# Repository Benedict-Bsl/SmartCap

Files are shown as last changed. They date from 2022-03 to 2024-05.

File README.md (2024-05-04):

# SmartCap is an IOT device
as a proof of concept device, it was aim to demonstate how with a few features,
a bottle could be smart in helping older people or pantient with periodic memory loss.

#### Features:
  - Cloud data loggingd
  - indicate the quantity/number of pills incide the bottle on mobile phone
  - allow substraction of remaining pills
  - notify the user the time frame for the next dosage
  - notify when the bottle is empty.
  - gps location and buzzer alarm sound, incase the bottle is misplaced or lost.

#### Folder contents:
  - TrackRXFirmware_noSerial : complete device firmware
  - TraCkRXFirmware : debugging code
  - Platformio : an extension for mobile network connectivity with a gsm module
  - Misceleanious: backup and obsole files
  - Firware : different firmware for different modules such as gsm gps
  - Documents : in relation of the developement process
  - DFRobot_ID809-master : library for finger print sensor
  - d1Mini_serverAccess : Cloud server access firmware
  - cv : dataset for pill image dettection
  - circuitry : circuit and related files
##### :) don't mind the huge size of the bottle ( or the cap(the green/white thing)... it's only a prototype ... ahaha, wait,.. it's a proof of concepts!
The above project is proprietary/private , for non commercial usage. Make sure you site the author in any related work. 
Interests, critics...? on the project?, 
please contact the author: benobusole@gmail.com | migarajun@outlook.com

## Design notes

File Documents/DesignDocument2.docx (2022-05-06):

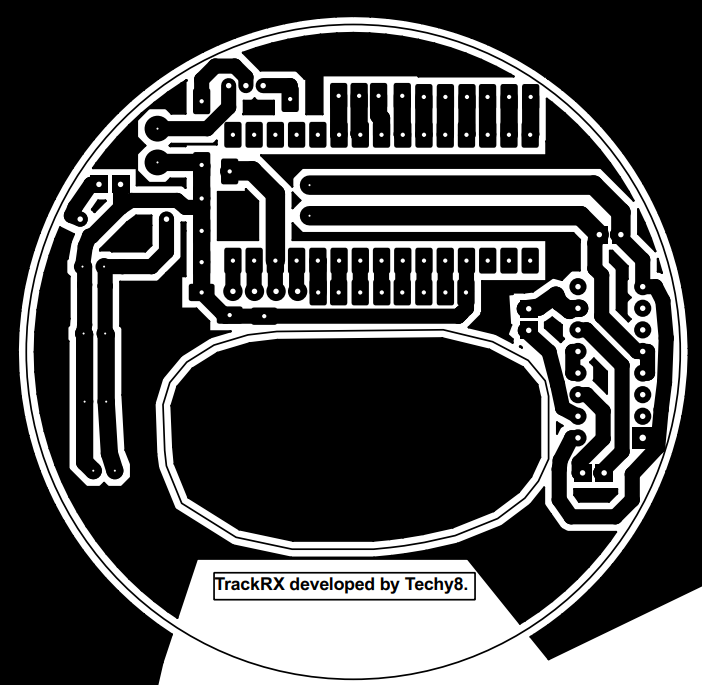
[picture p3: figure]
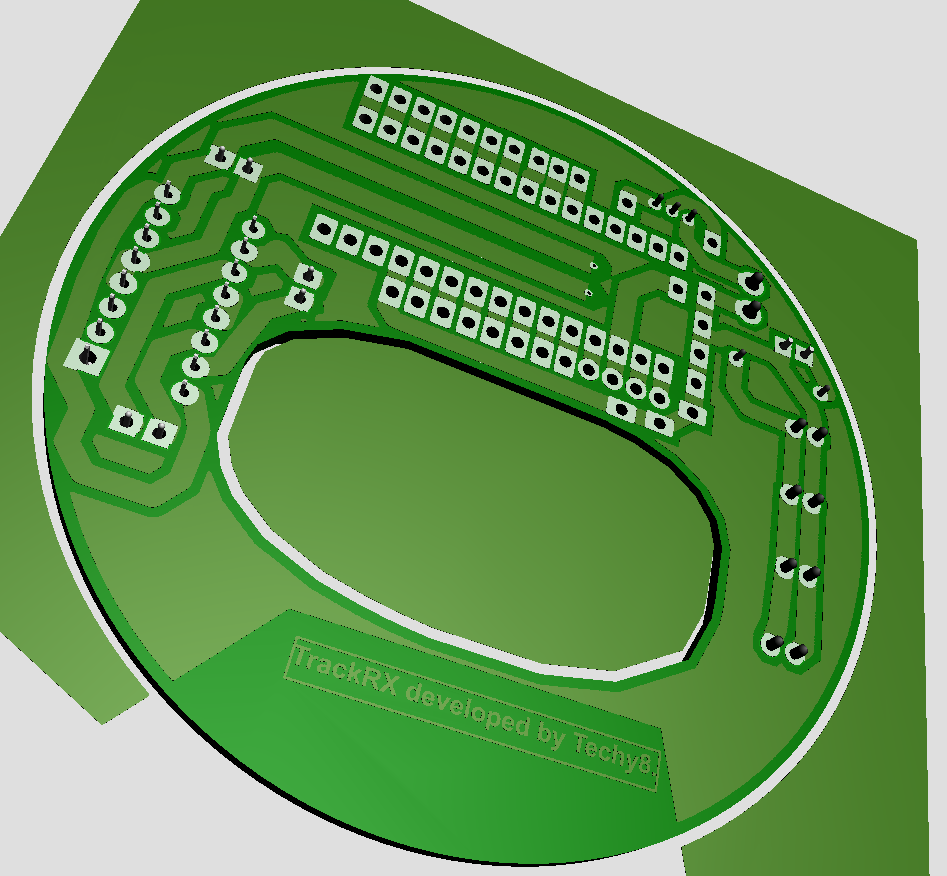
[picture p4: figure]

Main controller Power supply route Motor/locking control Sensors and Communication Section (net, gps..) | Printed Circuit Board | This is the main circuit board for the trackRX cap design with different components connected together as shown.

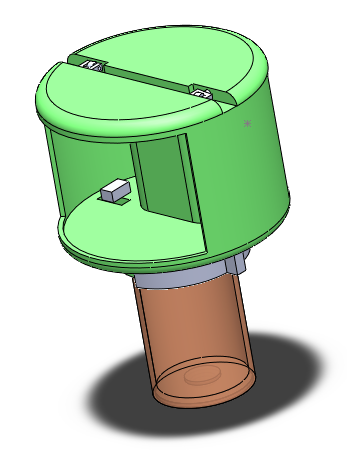
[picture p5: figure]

| Cup designs | The current cup design, with the front, back and top.

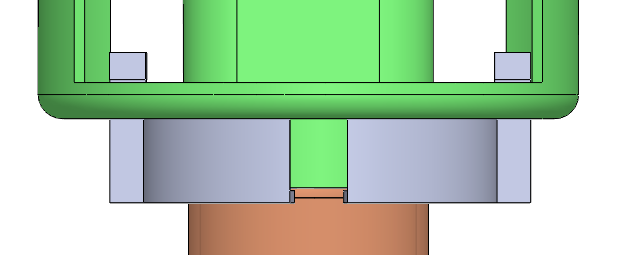
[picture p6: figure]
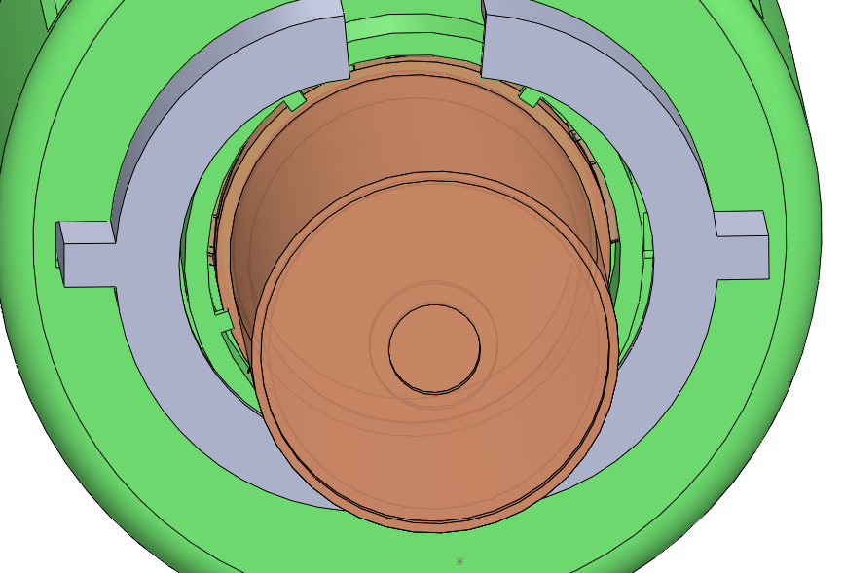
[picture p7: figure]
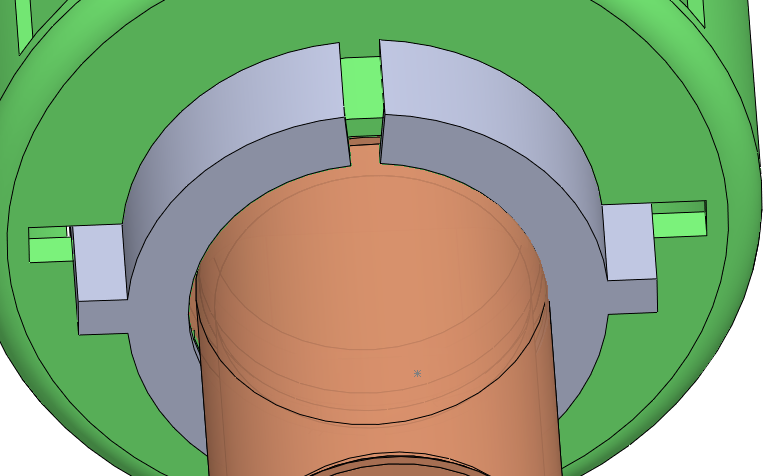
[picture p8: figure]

Open Front Closed | Bottom lock Mechanism | The current bottom mechanism design. the lock is remotely activated from the dashboard.

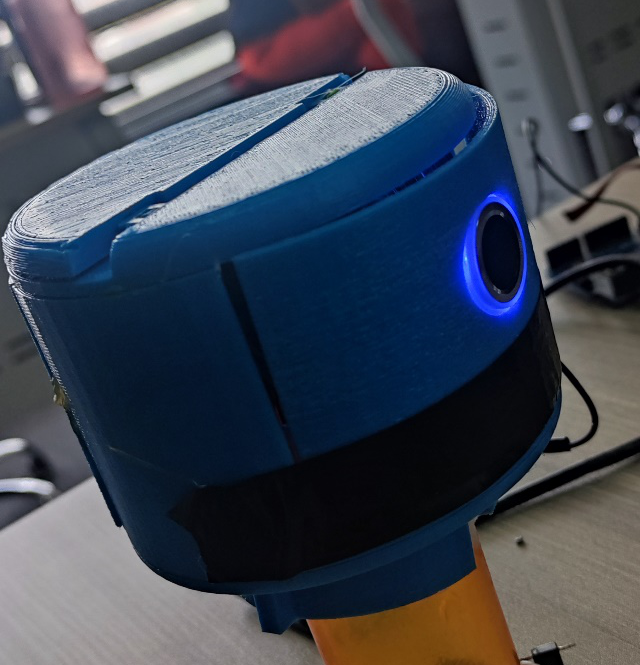
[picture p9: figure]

| Device during trial(current state). | Smart cap.

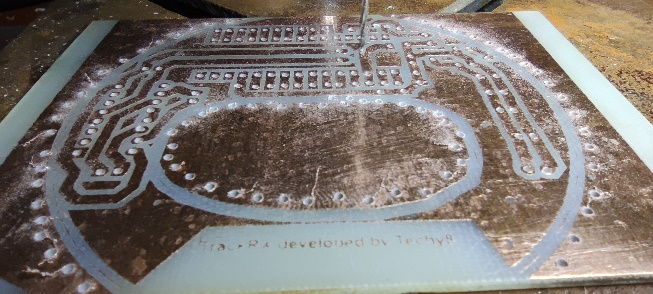
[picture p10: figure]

| Drilling of the trackRX pcB | TrackRX pcb.

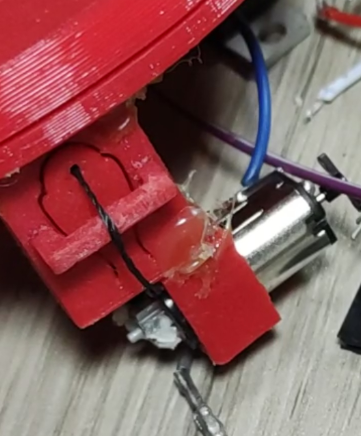
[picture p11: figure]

| On device top locking mechanism. (Early version) | Attract and retract based on given command.

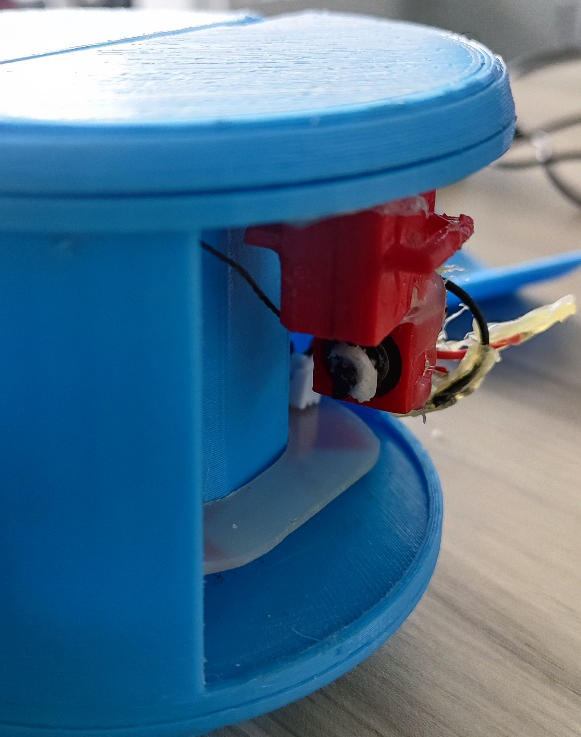
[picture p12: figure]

| Top Locking mechanism | Closed(if no fingerprint has been detected)

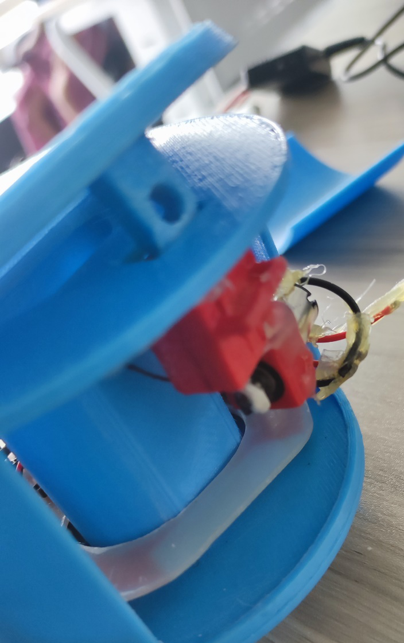
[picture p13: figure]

| Top locking Mechanism | Opened if finger print has been identified.

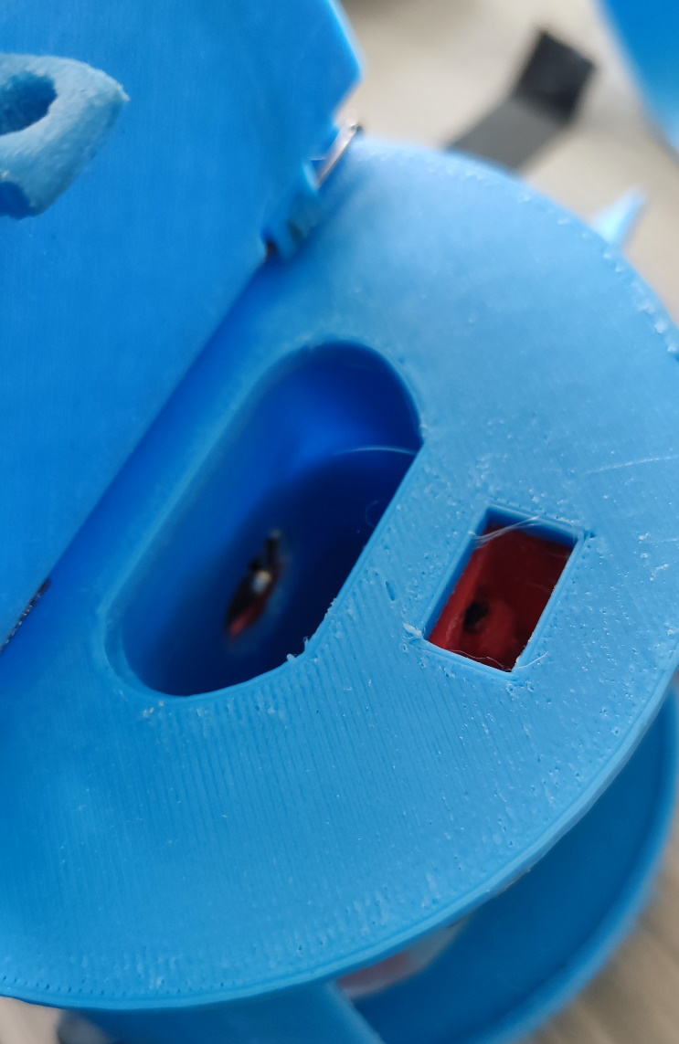
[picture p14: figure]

Sensory Point | Pills extraction point | Sensor included below (later will be covered with transparent glass)

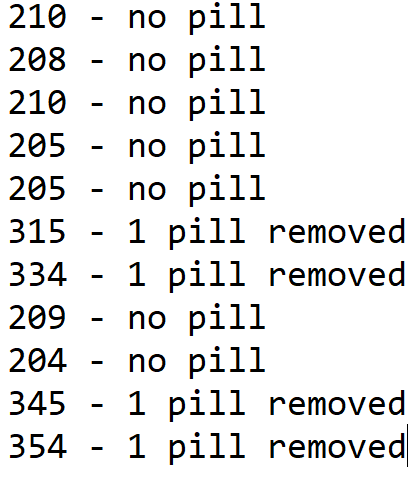
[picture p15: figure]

| Sensor output variations. | From 210-300 no pills have been detected From 310, 340 etc., a pill has been detect coming out of the bottle.

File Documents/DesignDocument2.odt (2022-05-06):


Main controller Power supply route Motor/locking control Sensors and Communication Section (net, gps..) | Printed Circuit Board | This is the main circuit board for the trackRX cap design with different components connected together as shown.


| Cup designs | The current cup design, with the front, back and top.


Open Front Closed | Bottom lock Mechanism | The current bottom mechanism design. the lock is remotely activated from the dashboard.


| Device during trial | Smart cap.


| Drilling of the trackRX pcB | TrackRX pcb.


| On device top locking mechanism | Attract and retract based on given command.

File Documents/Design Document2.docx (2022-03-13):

POC DESIGN DOCUMENT

For a smart cup on a bottle.

FEBRUARY 22, 2022

TECHY8

# Introduction

This document specifies key conceptual design for a smart pill cup, proof of concept design. The smart cup will be able to provide features such as: keeping track of the cup opening/closing, fingerprint reader, dosage trackage, content counter of the pills inside the bottle to which it is attached, and bottle location signaling; all provided to a website or a mobile application.

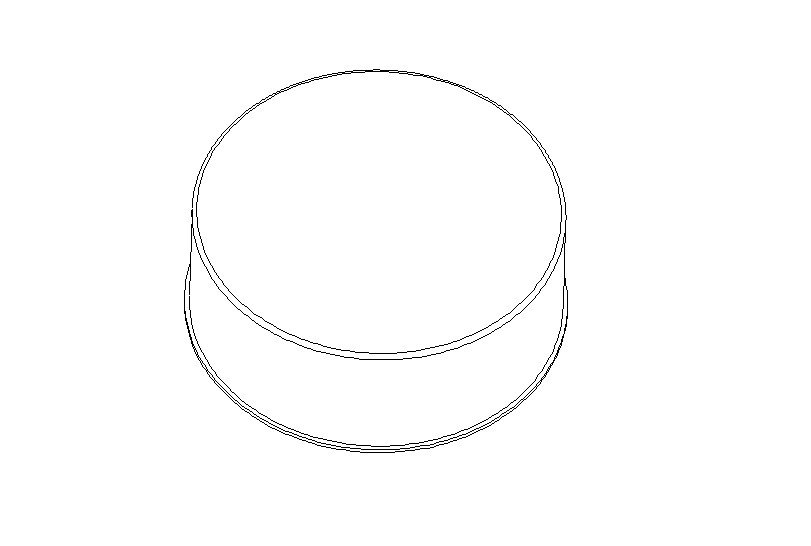
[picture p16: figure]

Figure 1 : POC cup

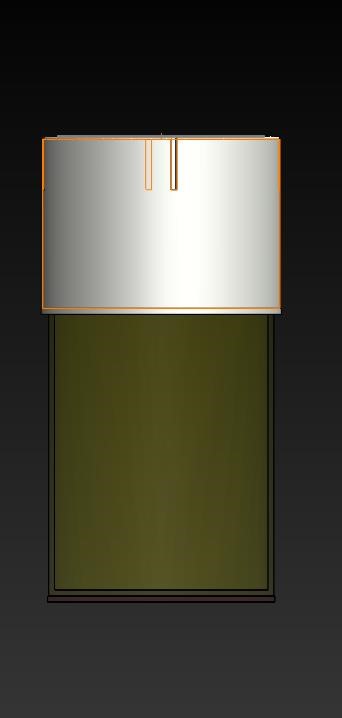
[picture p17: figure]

Figure 2 Cup on bottle

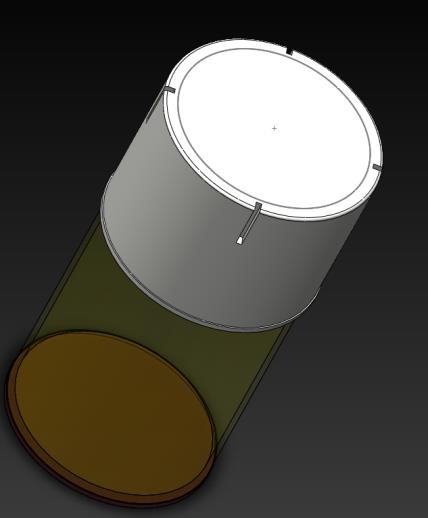
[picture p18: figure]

Figure 3 Cap and bottle (view)

## Tracking Cap Opening

A trigger switch placed on the cup will be able to detect when the bottles’ cup is opened or closed. The cup can only be opened if the fingerprint has successfully identified the owner or patient to whom the bottle belongs to.

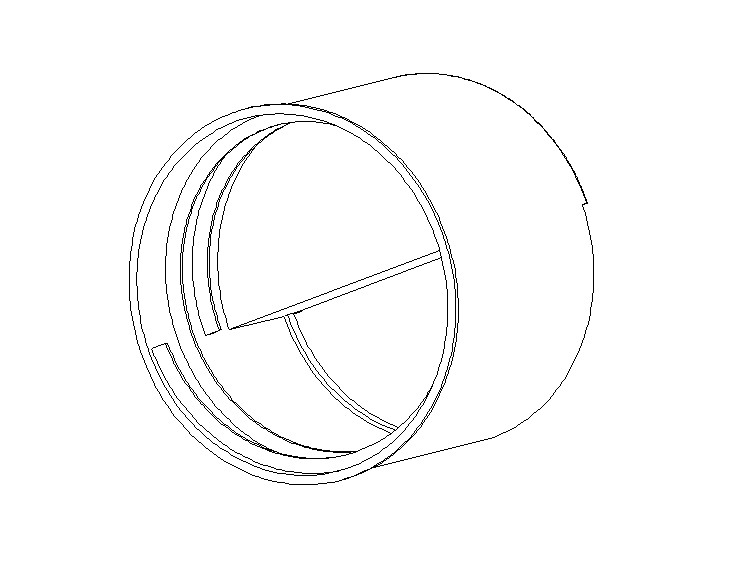
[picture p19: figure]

C

ont

act

switch

Figure 4 : Cup thread

## Finger print recognition

The finger print sensor, placed upon the cup will be able to identify the cap owner and that only, after the biometrical data has been retrieved and assured to be genuine, then a signal will be released by an imbedded microcontroller that will enable the locking mechanism of the bottle to be opened.

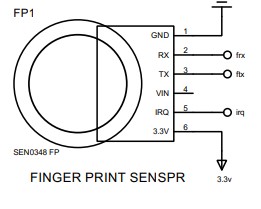
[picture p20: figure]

Figure 5 Finger print sensor

Programmable biometrics lock on the cap will prevent anyone other than the User to open the bottle.

## Track Dosage

Depending of the dosage set by the physician, a reminder will be provided from the handled phone so as to know exactly when to take the medicine, the last time it was taken and the next time it is supposed to.

## Content Counter

The counter will enable the User to know how much content has remained in the bottle and how many have been taken out.

A pressure sensor detects the amount of pressure applied to it, and the processing is done using the embedded microcontroller and that data is then shared with the phone so as to notify the user how many pills have remained in the bottle.

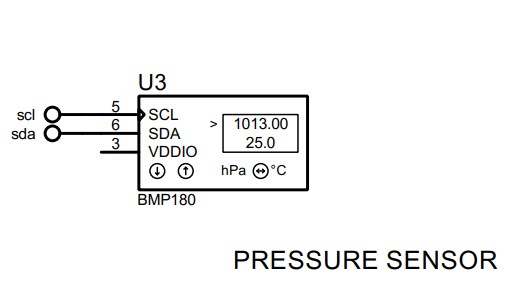
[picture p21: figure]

Figure 6 force/ pressure/ weight sensor

## Bottle Locating Signal Bottle

Locating signal to enable the User to locate their pills bottle should they forget or misplaced it. With the bottle allocating Single, a buzzer or a micro-speaker could be powered on and output a signal which will be triggered from the handled phone.

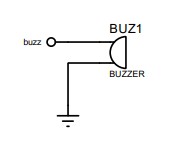
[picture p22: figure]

Figure 7 Buzzer / speaker for bottle signaling the location

## Sync to the Mobile App

via WIFI module through the microcontroller, all the data described above will be sent to the cold, and then from there, the data will be retrieved by the mobile phone or a personal computer.

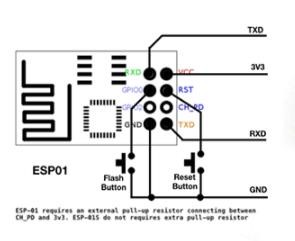
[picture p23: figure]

Figure 8 WIFI module to send data in the server/cloud

## Schematic diagram

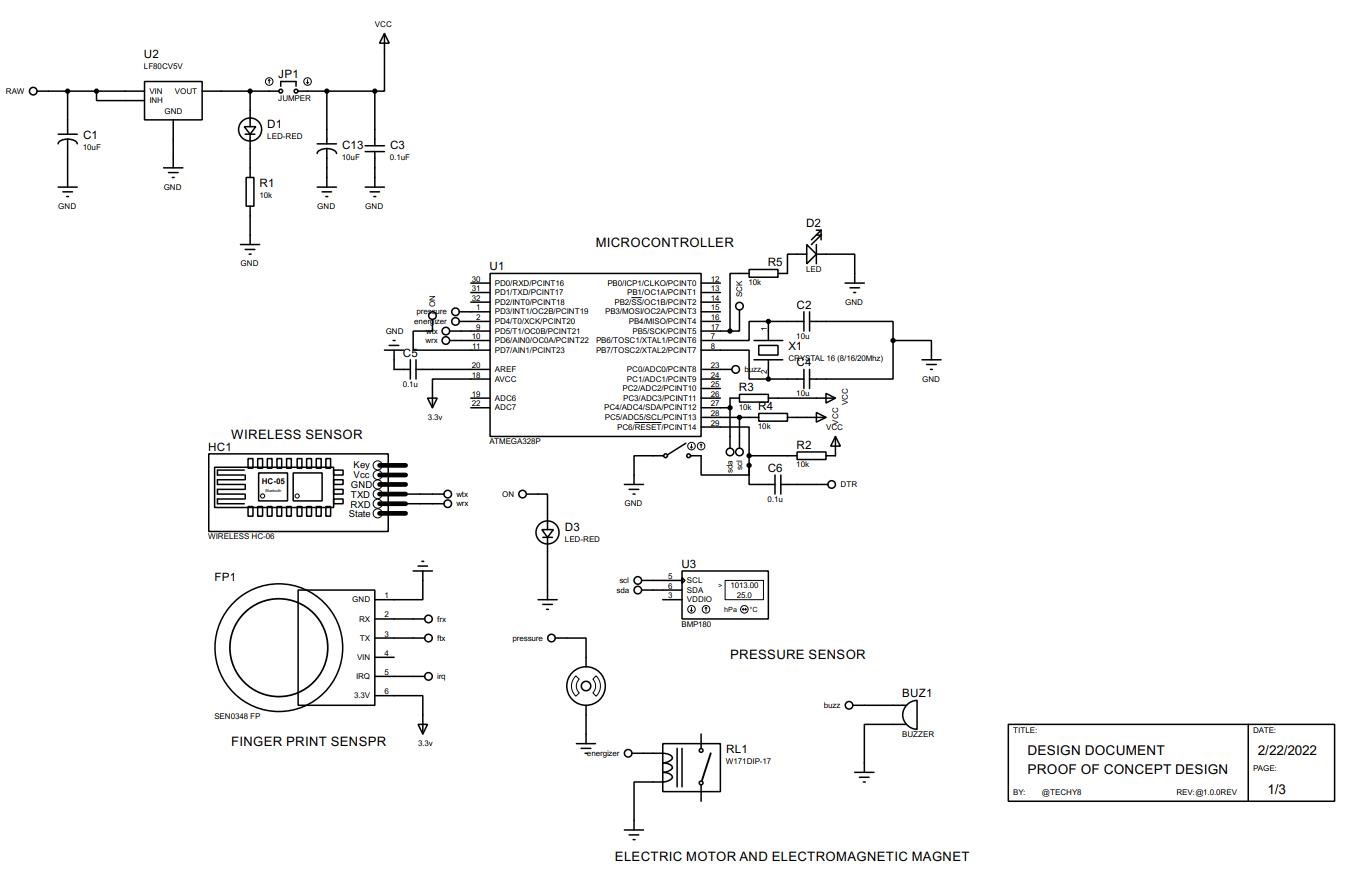
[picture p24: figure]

Figure 9 Schematic diagram

Note: The life span of the battery usually depends upon the devices to which it’s connected to. For the case of this POC design, much is still under development and different parameters are being looked up to set and to know how long could the battery truly last. Development is being conducted, and once enough is known about this feature, a report will be issued. But as a test and battery efficiencies are being conducted.

We are optimistic, trustful and sure; we will achieve the best results. When it comes to the bulkiness of the cup, this will greatly differ with the production product. This design will be huge due to the number of different boards used. But as soon as we will be heading to production, the size will greatly be reduced due to most/all components being on a single circuit board.

## Components ordered with respective features

Components | Feature
Capacitive finger print sensor | Biometric finger print recognition
Capacitive pressure/force sensor | For weighting the content of the bottle and understand how many are there
AtMega microcontroller | For processing sensor data and sending information to the cloud
WIFI module esp8266 | internet module used to send data to the cloud so as to help phone and device synchronization.
Electronics components such as diode, led, resistors and wiring etc.… | Help in interfacing sensors such as finger print sensor with the power and microcontroller
Weight sensor | Helps in measuring the number of pills due to individual weights.
Breadboard | Used to connect components during POC development.
Contact switch sensor | To understand, by using the microcontroller, when a cap is opened or closed.

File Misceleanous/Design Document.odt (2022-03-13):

poc design document

For a smart cup on a bottle.

February 22, 2022

techy8

Introduction

This document specifies key conceptual design for a smart pill cup, proof of concept design. The smart cup will be able to provide features such as: keeping track of the cup opening/closing, fingerprint reader, dosage trackage, content counter of the pills inside the bottle to which it is attached, and bottle location signaling; all provided to a website or a mobile application.

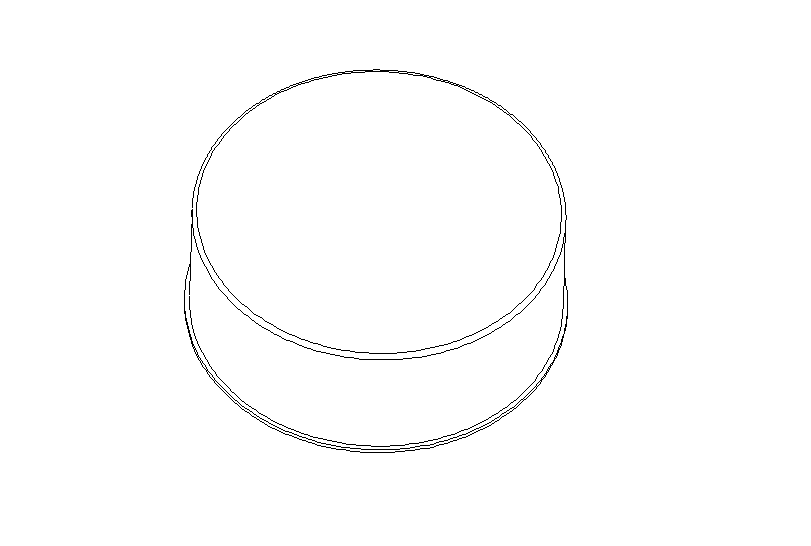
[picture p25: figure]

Figure 1 : POC cup

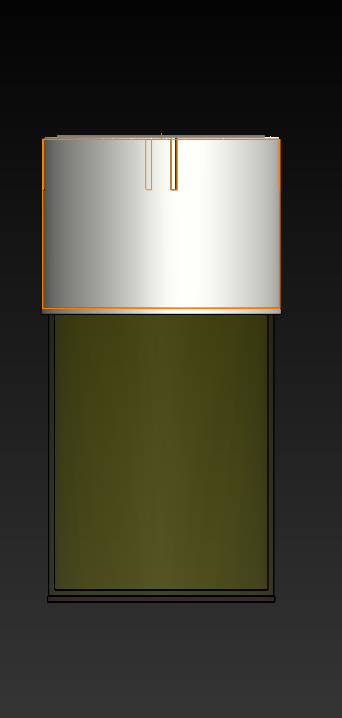
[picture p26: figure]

Figure 2 Cup on bottle


Figure 3 Cap and bottle (view)

Tracking Cap Opening

A trigger switch placed on the cup will be able to detect when the bottles’ cup is opened or closed. The cup can only be opened if the fingerprint has successfully identified the owner or patient to whom the bottle belongs to.

Contact switch


Figure 4 : Cup thread

Finger print recognition

The finger print sensor, placed upon the cup will be able to identify the cap owner and that only, after the biometrical data has been retrieved and assured to be genuine, then a signal will be released by an imbedded microcontroller that will enable the locking mechanism of the bottle to be opened.


Figure 5 Finger print sensor

Programmable biometrics lock on the cap will prevent anyone other than the User to open the bottle.

Track Dosage

Depending of the dosage set by the physician, a reminder will be provided from the handled phone so as to know exactly when to take the medicine, the last time it was taken and the next time it is supposed to.

Content Counter

The counter will enable the User to know how much content has remained in the bottle and how many have been taken out.

A pressure sensor detects the amount of pressure applied to it, and the processing is done using the embedded microcontroller and that data is then shared with the phone so as to notify the user how many pills have remained in the bottle.


Figure 6 force/ pressure/ weight sensor

Bottle Locating Signal Bottle

Locating signal to enable the User to locate their pills bottle should they forget or misplaced it. With the bottle allocating Single, a buzzer or a micro-speaker could be powered on and output a signal which will be triggered from the handled phone.


Figure 7 Buzzer / speaker for bottle signaling the location

Sync to the Mobile App

via WIFI module through the microcontroller, all the data described above will be sent to the cold, and then from there, the data will be retrieved by the mobile phone or a personal computer.


Figure 8 WIFI module to send data in the server/cloud

Schematic diagram


Figure 9 Schematic diagram

Note: The life span of the battery usually depends upon the devices to which it’s connected to. For the case of this POC design, much is still under development and different parameters are being looked up to set and to know how long could the battery truly last. Development is being conducted, and once enough is known about this feature, a report will be issued. But as a test and battery efficiencies are being conducted.

We are optimistic, trustful and sure; we will achieve the best results. When it comes to the bulkiness of the cup, this will greatly differ with the production product. This design will be huge due to the number of different boards used. But as soon as we will be heading to production, the size will greatly be reduced due to most/all components being on a single circuit board.

Components ordered with respective features

Components | Feature
Capacitive finger print sensor | Biometric finger print recognition
Capacitive pressure/force sensor | For weighting the content of the bottle and understand how many are there
AtMega microcontroller | For processing sensor data and sending information to the cloud
WIFI module esp8266 | internet module used to send data to the cloud so as to help phone and device synchronization.
Electronics components such as diode, led, resistors and wiring etc.… | Help in interfacing sensors such as finger print sensor with the power and microcontroller
Weight sensor | Helps in measuring the number of pills due to individual weights.
Breadboard | Used to connect components during POC development.
Contact switch sensor | To understand, by using the microcontroller, when a cap is opened or closed.

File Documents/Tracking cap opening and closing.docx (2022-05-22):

Tracking cap opening and closing


Biometric locking mechanism. opens if the finger has been detected and accepted


Content counter


Pill bottle allocating signal

Synch to mobile app. connecting to TrackRx server.


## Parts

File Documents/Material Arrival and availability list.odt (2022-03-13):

Description: Item receive: 11:40, 25 February, 2022 | | Item name and description | Number
| Actuator | Dc motor with connection line + gear | 10 pairs
| Communication | ESP8266 Serial WIFI Module Transceiver 3.3v | 4
| Battery | PKCELL LP503035 3.7v 500mAh | 1
| Driver | Hx711 drivers | 2
| Wire | HiLetgo wires | 120
| Driver | Sparkfun Load cell Amplifier | 1
| Sensor | Force sensitive Resistor | 1
| Microcontroller | HiLetgo Leornardo Micro USB | 3
| Components | Electronic Assortment components kit from MegaElectronic | 1900
| Wire | Test lead set with alligator clips | 20
| Sensor | 300g weighing electronic sensor | 1
| Sensor | Load sensor: 0-100g weighting | 1
| Capture | DFRobot Capacitive Fingerprint Scanner/Sensor SEN0348 | 1
| Actuator | NW Motor 9161C | 5
| Battery | 3.7 v 100mAh Lipo ProtoX , Synao | 2
| Board | Solderless BreadBoad RexQualis | 4
| Bottle | CVS Bottle | 5
| Bottle | Advil | 1
| Cup | Push down & open | 1
| Capture | DEALPEAK DC 3.3v R503 circuit light Ea Finger print Scanner/Sensor | 1
| Microcontroller | Development board 5v 16Mhz | 1
| Communication | DEVMO D1 PRO De..ible with WeMos AU867-mini D1 PRO DM-DM | 1

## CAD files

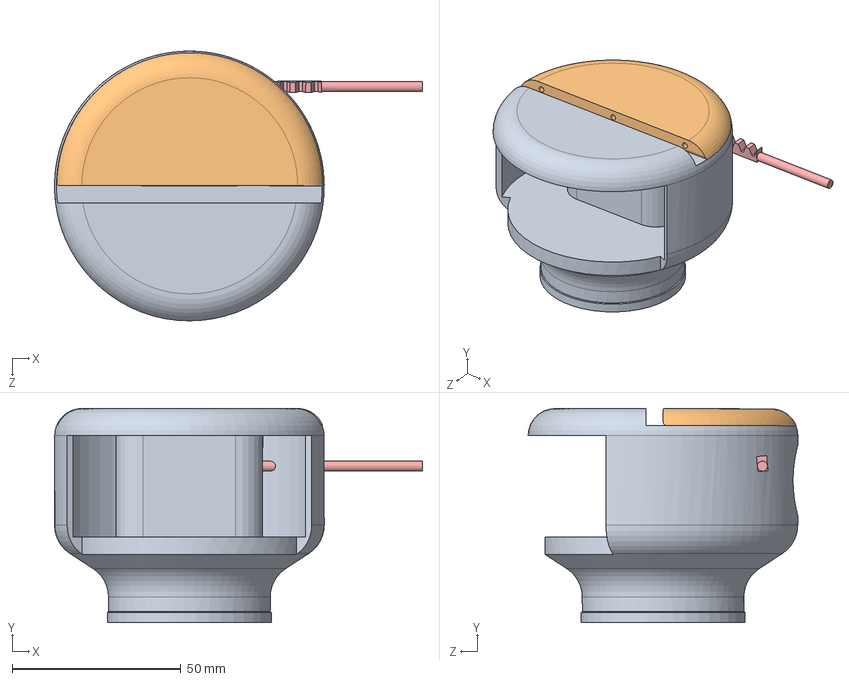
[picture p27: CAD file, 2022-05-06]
Designs/Designs/Assemblies/Assem_With_Top_lockMechanism.SLDASM
109.1 x 63.5 x 80.0 mm
CupVersion4D6_withLocksM_2_fp&mt
Top_LockMechan_CupVersion4D6_withLocksM_2_fp&mt
motor
rotation axis gear
lockee
holder of rotation axis gear
MotorThread

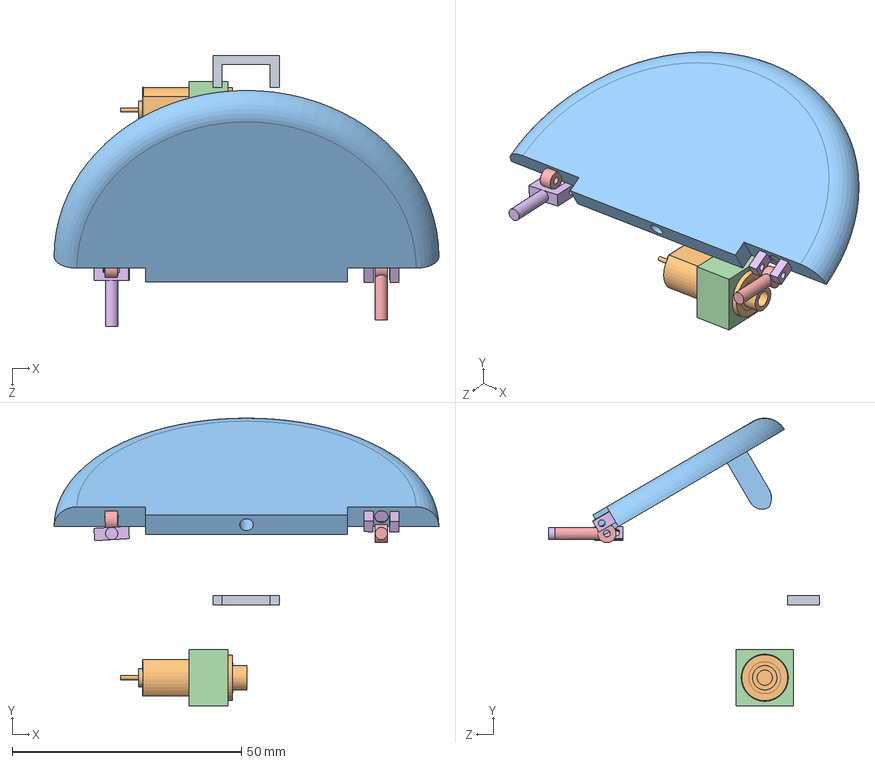
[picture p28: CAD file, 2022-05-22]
Designs/Designs/Thursday 13 04 2022/Assem2.SLDASM
84.0 x 62.8 x 59.1 mm
a
servoMotor_A35A703
UP_lock_CapDesign_Version6
Holder_servoMotor_A35A703

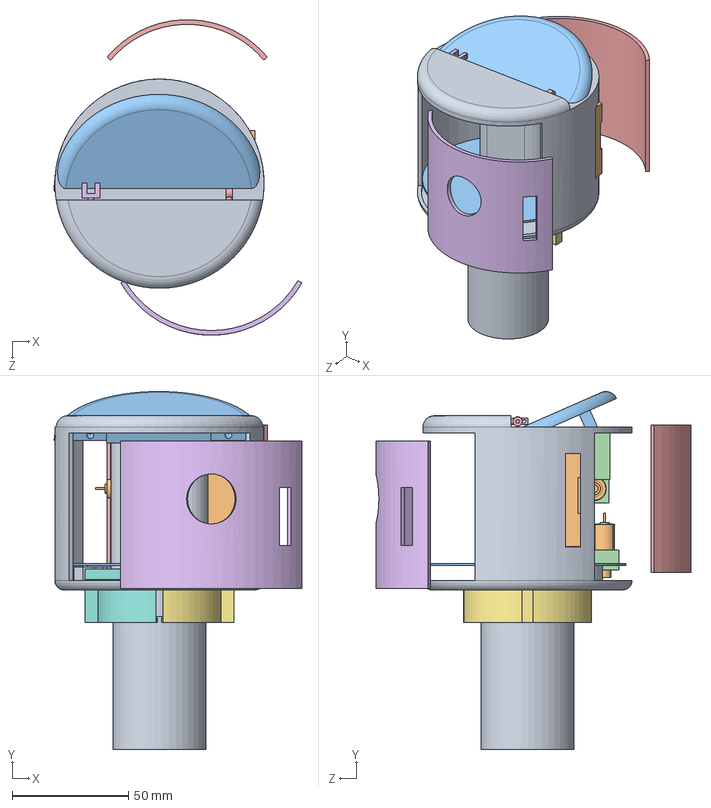
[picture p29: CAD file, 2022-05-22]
Designs/Monday 25 04 2022/Assem3.SLDASM
106.6 x 154.0 x 135.6 mm
bigger_cap3
servoMotor_A35A703 x 2
UP_lock_CapDesign_Version6_L
Holder_servoMotor_A35A703 x 2
locks_bottom
locks_bottom_2
Bottle)design
gsm
separetor_capBottom
loCK_WithThin_for_biggerCap
bigger_cap3_smallCover
bigger_cap3_FingerPrintPart

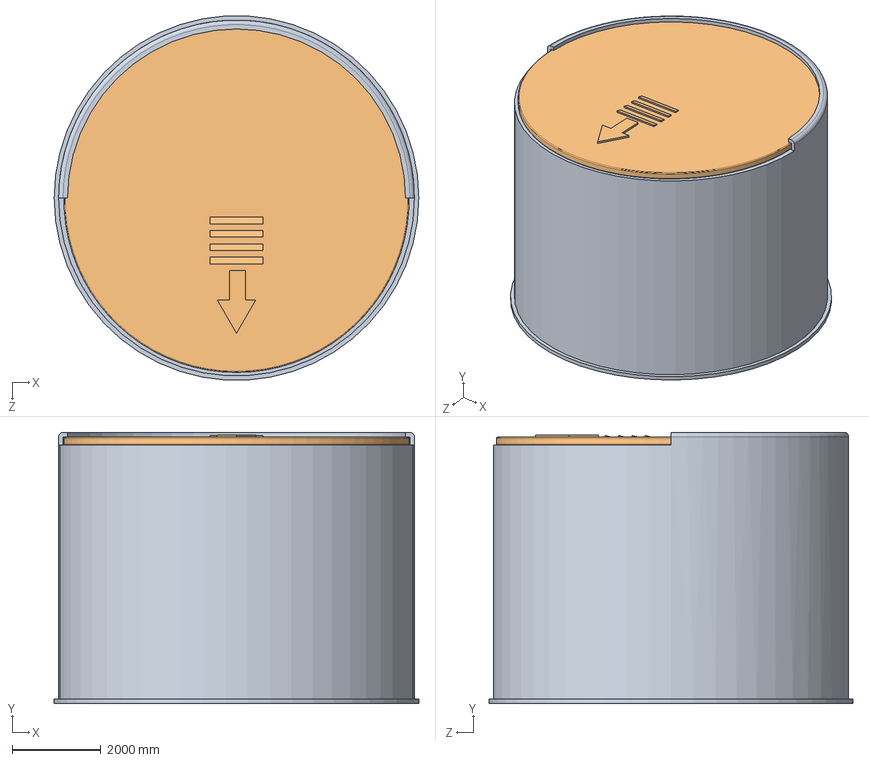
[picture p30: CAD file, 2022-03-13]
Misceleanous/Backup (1) of TopCupv4.SLDASM
8200.0 x 6100.0 x 8183.8 mm
cupModSlide2
sliddingSection
magnet x 7

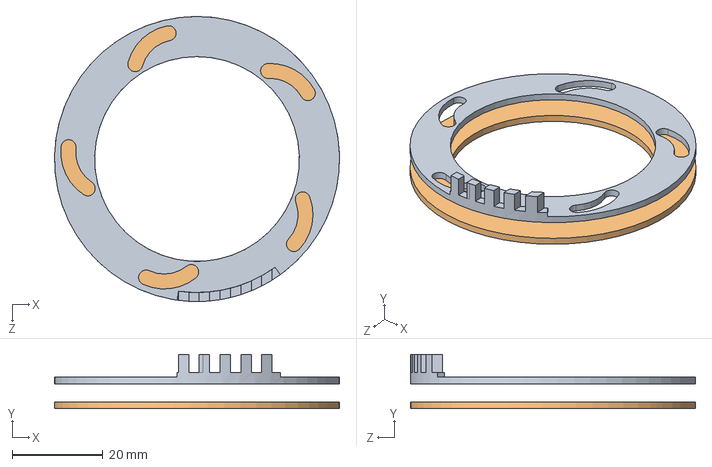
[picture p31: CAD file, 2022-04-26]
Designs/Designs/Assemblies/Assem_me_idea.SLDASM
63.0 x 12.0 x 63.0 mm
retractable_rotator
retractable_anOtherOne

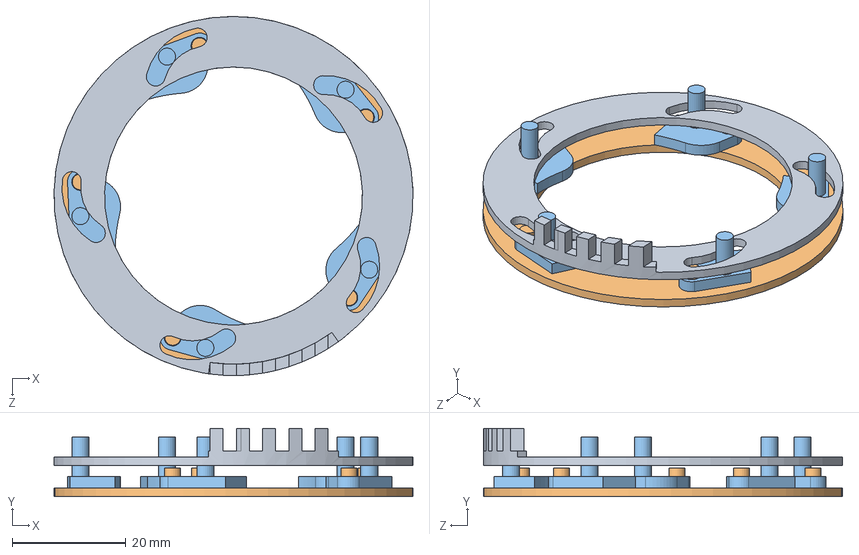
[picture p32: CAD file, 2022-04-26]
Designs/Designs/Assemblies/Assem_KVO_idea.SLDASM
63.0 x 12.0 x 63.0 mm
retractable_rotator
retractable2_Vd
Retractee x 5

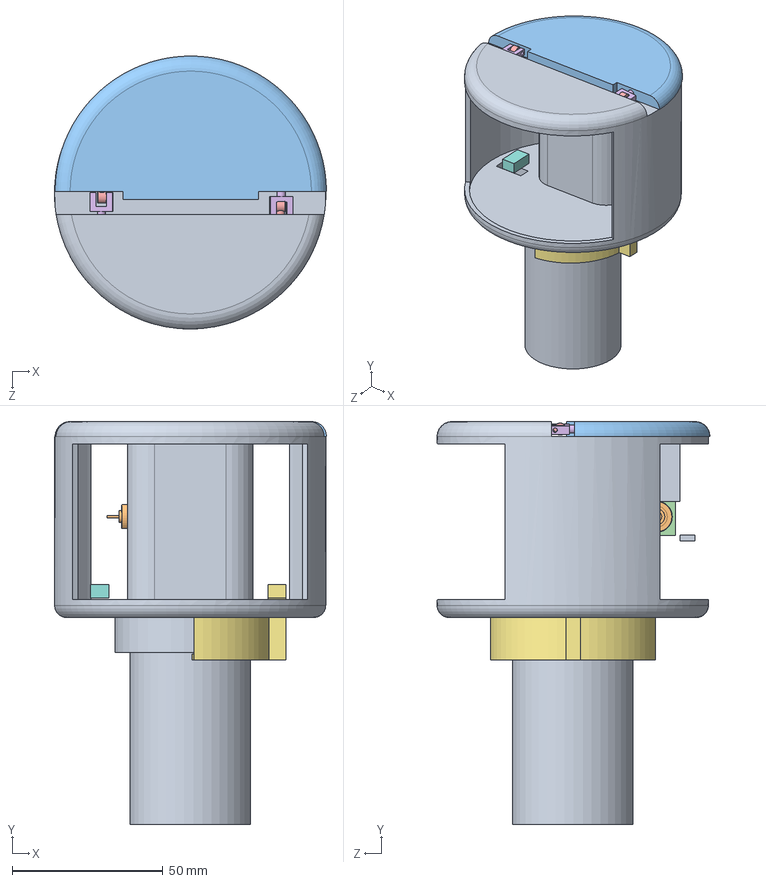
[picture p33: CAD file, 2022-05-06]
Designs/Designs/Monday 25 04 2022/Assem2.SLDASM
90.2 x 133.6 x 90.5 mm
bigger_cap
servoMotor_A35A703
UP_lock_CapDesign_Version6_L
Holder_servoMotor_A35A703
locks_bottom
locks_bottom_2
Bottle)design

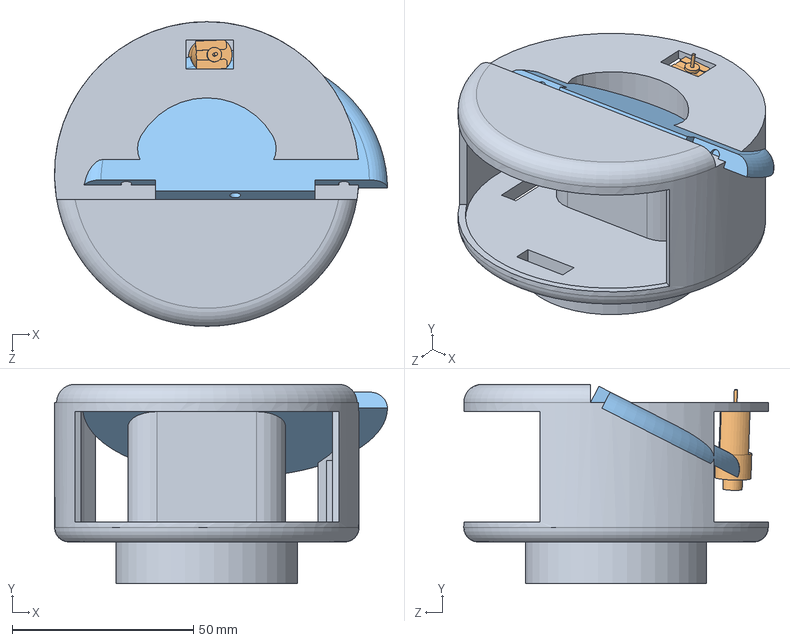
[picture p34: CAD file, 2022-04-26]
Designs/Designs/Thursday 13 04 2022/Backup (2) of Assem2.SLDASM
91.8 x 55.0 x 84.0 mm
CapDesign_Version6
servoMotor_A35A703
UP_lock_CapDesign_Version6

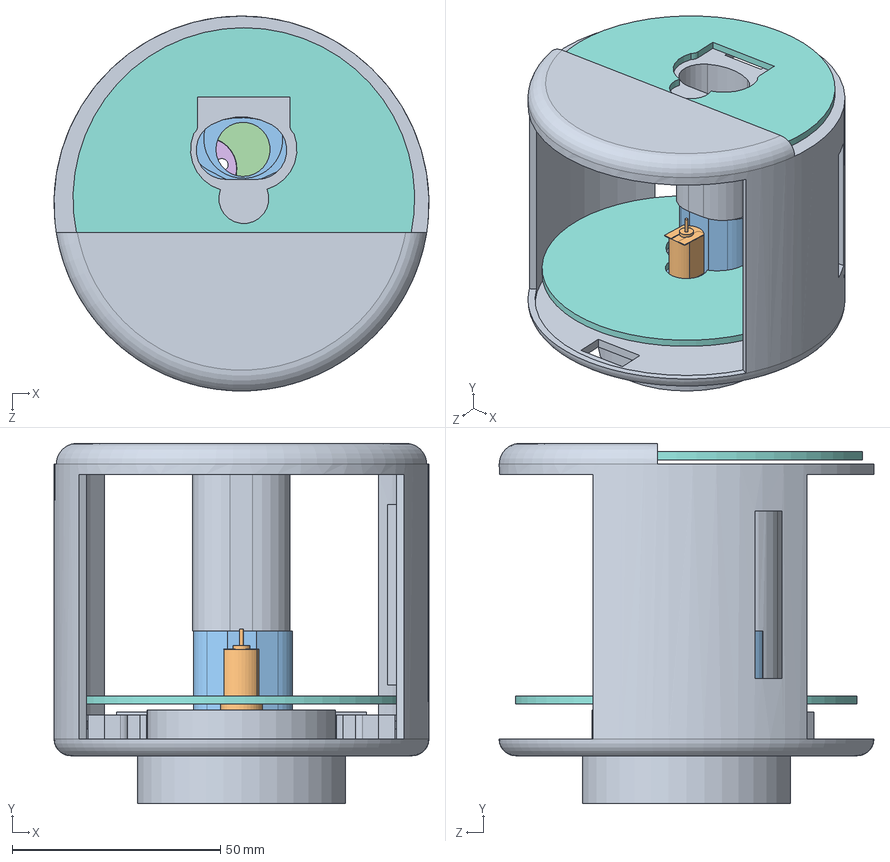
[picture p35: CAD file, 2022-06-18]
Designs/Tuesday 15 06 2022/Assem_autoPill_disp.SLDASM
90.0 x 86.5 x 90.0 mm
bigger_cap4_auto_pillDisp
servoMotor_A35A703
rotatingDisk2
Rotate_pillSizeVar
separatttttttt
pillSize
proximitySensor
PCB_From_17 06 3d x 2

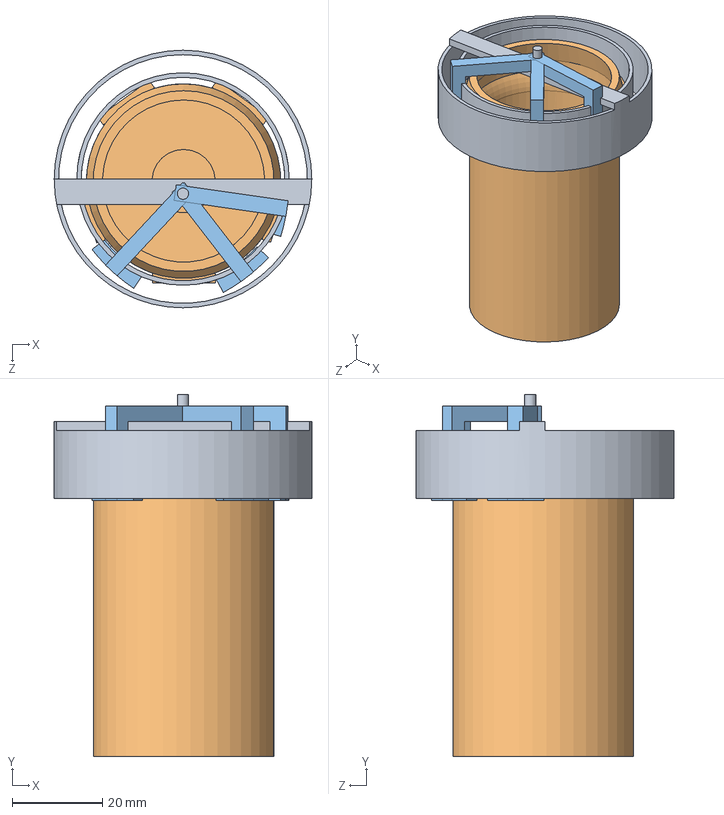
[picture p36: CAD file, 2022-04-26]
Designs/Designs/Assemblies/Bottom_lock_assembly.SLDASM
57.0 x 80.1 x 57.0 mm
Rotorara
Bottle)design
Rotator_1 x 3

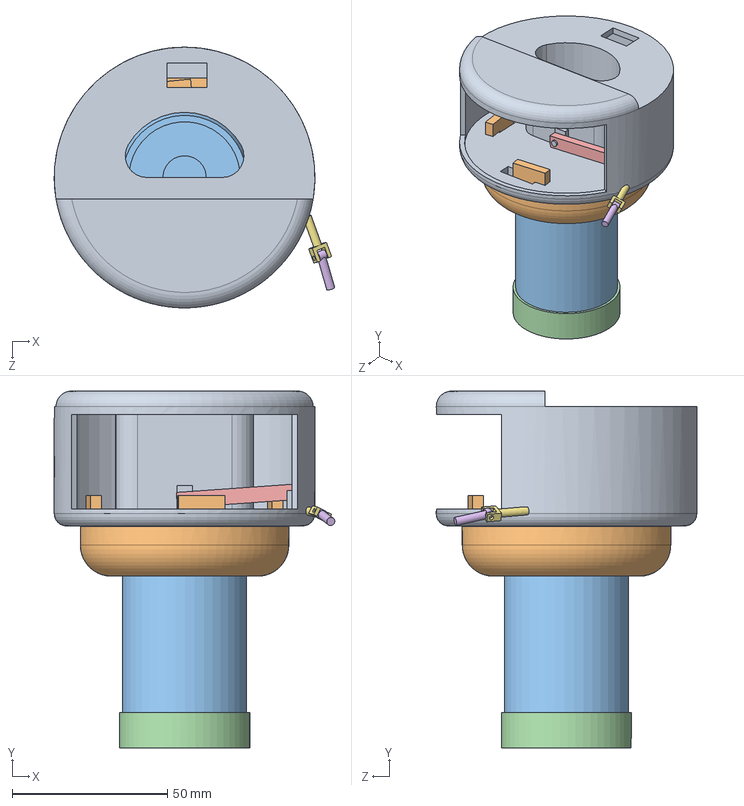
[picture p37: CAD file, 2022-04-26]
Designs/Designs/Monday 04 04 2022/Backup (1) of Assem1.SLDASM
90.4 x 115.0 x 84.0 mm
CapDesign_Version5
Bottle)design
LockInside

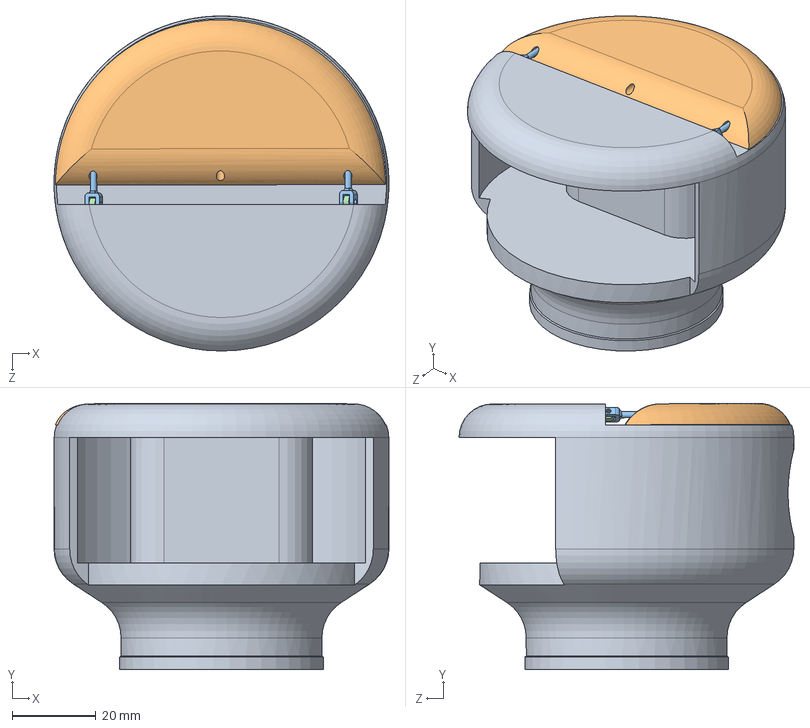
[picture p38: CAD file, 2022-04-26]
Designs/Designs/Assemblies/Backup (5) of Assem_With_Top_lockMechanism.SLDASM
80.0 x 63.5 x 80.0 mm
CupVersion4D6_withLocksM_2_fp&mt
Top_LockMechan_CupVersion4D6_withLocksM_2_fp&mt
hinge2 x 2
hinge1 x 2

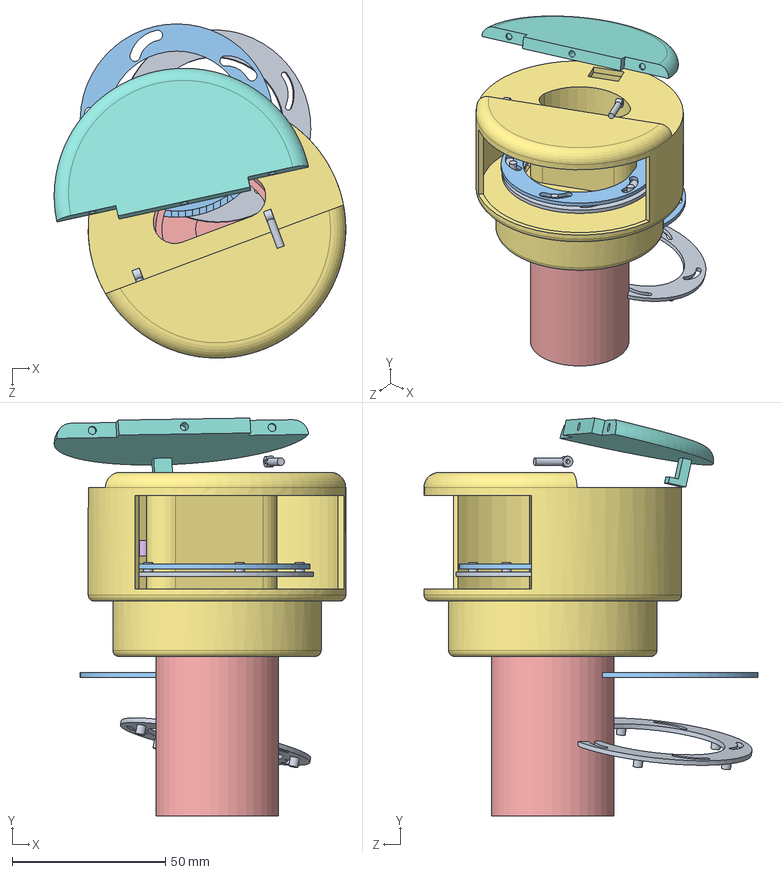
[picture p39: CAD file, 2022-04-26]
Designs/Designs/STL files/New/Rectractor_Assembly1.SLDASM
95.1 x 129.7 x 108.9 mm
retractable2 x 2
Retractee
retractable_rotator x 2
Rectrator_holder
Bottle)design
MotorThread
CapDesign_Version2
UP_lock_CapDesign_Version2
hinge1 x 2

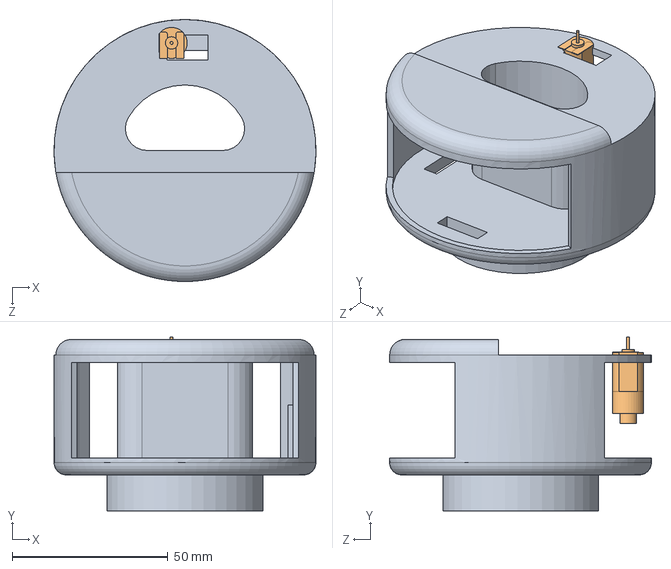
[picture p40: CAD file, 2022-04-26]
Designs/Designs/Thursday 13 04 2022/Backup (4) of Assem2.SLDASM
84.0 x 55.7 x 84.0 mm
CapDesign_Version6
servoMotor_A35A703

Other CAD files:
Designs/Assemblies/Hinge_Assem1.SLDASM
Designs/Designs/Assemblies/Hinge_Assem1.SLDASM
Designs/CupVersion4D6_withLocksM_2_fp&mt.SLDPRT
Designs/Designs/Arduino_Nano.SLDPRT
Designs/Designs/Assem_With_Top_lockMechanism.SLDASM
Designs/Designs/Assemblies/Assem1_OP.SLDASM
Designs/Designs/Assemblies/Backup (1) of Assem_With_Top_lockMechanism.SLDASM
Designs/Designs/Assemblies/Backup (1) of CapVersion4_complete.SLDASM
Designs/Designs/Assemblies/Backup (1) of Hinge_Assem1.SLDASM
Designs/Designs/Assemblies/Backup (10) of Assem_With_Top_lockMechanism.SLDASM
Designs/Designs/Assemblies/Backup (2) of Assem_With_Top_lockMechanism.SLDASM
Designs/Designs/Assemblies/Backup (2) of Hinge_Assem1.SLDASM
Designs/Designs/Assemblies/Backup (3) of Assem_With_Top_lockMechanism.SLDASM
Designs/Designs/Assemblies/Backup (3) of Hinge_Assem1.SLDASM
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

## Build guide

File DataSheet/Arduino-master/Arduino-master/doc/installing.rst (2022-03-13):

Installing
==========

Boards Manager
--------------

This is the suggested installation method for end users.

Prerequisites
~~~~~~~~~~~~~

-  Arduino 1.6.8, get it from `Arduino
   website <https://www.arduino.cc/en/Main/OldSoftwareReleases#previous>`__.
-  Internet connection
-  Python 3 interpreter (Mac/Linux only, Windows installation supplies its own)

Instructions
~~~~~~~~~~~~

-  Start Arduino and open Preferences window.
-  Enter
   ``https://arduino.esp8266.com/stable/package_esp8266com_index.json``
   into *Additional Board Manager URLs* field. You can add multiple
   URLs, separating them with commas.
-  Open Boards Manager from Tools > Board menu and find *esp8266*
   platform.
-  Select the version you need from a drop-down box.
-  Click *install* button.
-  Don't forget to select your ESP8266 board from Tools > Board menu
   after installation.

For more information on the Arduino Board Manager, see:

- https://www.arduino.cc/en/guide/cores

Using git version
-----------------

This is the suggested installation method for contributors and library
developers.

Prerequisites
~~~~~~~~~~~~~

-  Arduino 1.6.8 (or newer, current working version is 1.8.5)
-  git
-  Python 3.x (https://python.org)
-  terminal, console, or command prompt (depending on your OS)
-  Internet connection
-  Uninstalling any core version installed via Board Manager

Instructions - Windows 10
~~~~~~~~~~~~~~~~~~~~~~~~~
- First, make sure you don't already have an ESP8266 core version installed 
  using the Board Manager (see above). If you do, uninstall it from the 
  Board Manager before proceeding. It is also advisable to erase the Arduino15 
  contents.

- Install git for Windows (if not already; see https://git-scm.com/download/win)

-  Open a command prompt (cmd) and go to Arduino default directory. This is typically the
   *sketchbook* directory (usually ``C:\users\{username}\Documents\Arduino`` where the environment variable ``%USERPROFILE%`` usually contains ``C:\users\{username}``)
   
-  Clone this repository into hardware/esp8266com/esp8266 directory.

   .. code:: bash
      
       cd %USERPROFILE%\Documents\Arduino\
       if not exist hardware mkdir hardware
       cd hardware
       if not exist esp8266com mkdir esp8266com
       cd esp8266com
       git clone https://github.com/esp8266/Arduino.git esp8266

   You should end up with the following directory structure in
   
   ``C:\Users\{your username}\Documents\``

   .. code:: bash

       Arduino
       |
       --- libraries
       --- hardware
           |
           --- esp8266com
               |
               --- esp8266
                   |
                   --- bootloaders
                   --- cores
                   --- doc
                   --- libraries
                   --- package
                   --- tests
                   --- tools
                   --- variants
                   --- platform.txt
                   --- programmers.txt
                   --- README.md
                   --- boards.txt
                   --- LICENSE

-  Initialize the submodules

   .. code:: bash

       cd %USERPROFILE%\Documents\Arduino\hardware\esp8266com\esp8266
       git submodule update --init   
  
  If error messages about missing files related to ``SoftwareSerial`` are encountered during the build process, it should be because this step was missed and is required.
  
-  Download binary tools

   .. code:: bash

       cd tools 
       python3 get.py

-  Restart Arduino

- If using the Arduino IDE for Visual Studio (https://www.visualmicro.com/), be sure to click Tools - Visual Micro - Rescan Toolchains and Libraries 

-  When later updating your local library, goto the esp8266 directory and do a git pull

   .. code:: bash

       cd %USERPROFILE%\Documents\Arduino\hardware\esp8266com\esp8266
       git status
       git pull

Note that you could, in theory install in ``C:\Program Files (x86)\Arduino\hardware`` however this has security implications, not to mention the directory often gets blown away when re-installing Arduino IDE. It does have the benefit (or drawback, depending on your perspective) - of being available to all users on your PC that use Arduino.

Instructions - Other OS
~~~~~~~~~~~~~~~~~~~~~~~

-  First, make sure you don't already have an ESP8266 core version installed 
   using the Board Manager (see above). If you do, uninstall it from the 
   Board Manager before proceeding. It is also advisable to erase the .arduino15 (Linux)
   or Arduino15 (MacOS) contents.

-  Open the console and go to Arduino directory. This can be either your
   *sketchbook* directory (usually ``<Documents>/Arduino``), or the
   directory of Arduino application itself, the choice is up to you.

-  Clone this repository into hardware/esp8266com/esp8266 directory.
   Alternatively, clone it elsewhere and create a symlink, if your OS
   supports them.

   .. code:: bash

       cd hardware
       mkdir esp8266com
       cd esp8266com
       git clone https://github.com/esp8266/Arduino.git esp8266

   You should end up with the following directory structure:

   .. code:: bash

       Arduino
       |
       --- hardware
           |
           --- esp8266com
               |
               --- esp8266
                   |
                   --- bootloaders
                   --- cores
                   --- doc
                   --- libraries
                   --- package
                   --- tests
                   --- tools
                   --- variants
                   --- platform.txt
                   --- programmers.txt
                   --- README.md
                   --- boards.txt
                   --- LICENSE

-  Initialize the submodules

   .. code:: bash

       cd esp8266
       git submodule update --init   
  
  If error messages about missing files related to ``SoftwareSerial`` are encountered during the build process, it should be because this step was missed and is required.

-  Download binary tools

   .. code:: bash
       
       cd tools
       python3 get.py

   If you get an error message stating that python3 is not found, you will need to install it (most modern UNIX-like OSes provide Python 3 as
   part of the default install).  To install you will need to use ``sudo yum install python3``, ``sudo apt install python3``, or ``brew install python3``
   as appropriate.  On the Mac you may get an error message like:

   .. code:: bash

       python3 get.py
       Platform: x86_64-apple-darwin
       Downloading python3-macosx-placeholder.tar.gz
       Traceback (most recent call last):
         File "/Library/Frameworks/Python.framework/Versions/3.7/lib/python3.7/urllib/request.py", line 1317, in do_open
           encode_chunked=req.has_header('Transfer-encoding'))
         ...
         File "/Library/Frameworks/Python.framework/Versions/3.7/lib/python3.7/ssl.py", line 1117, in do_handshake
           self._sslobj.do_handshake()
       ssl.SSLCertVerificationError: [SSL: CERTIFICATE_VERIFY_FAILED] certificate verify failed: unable to get local issuer certificate (_ssl.c:1056)

    This is because Homebrew on the Mac does not always install the required SSL certificates by default.  Install them manually (adjust the Python 3.7 as needed) with:

    .. code:: bash

        cd "/Applications/Python 3.7/" && sudo "./Install Certificates.command"

-  Restart Arduino

-  When later updating your local library, goto the esp8266 directory and do a git pull

   .. code:: bash

       cd hardware\esp8266com\esp8266
       git status
       git pull

Using PlatformIO
----------------

`PlatformIO <https://platformio.org?utm_source=arduino-esp8266>`__
is an open source ecosystem for IoT development with a cross-platform
build system, a library manager, and full support for Espressif
(ESP8266) development. It works on the following popular host operating
systems: macOS, Windows, Linux 32/64, and Linux ARM (like Raspberry Pi,
BeagleBone, CubieBoard).

- `What is PlatformIO? <https://docs.platformio.org/en/latest/what-is-platformio.html?utm_source=arduino-esp8266>`__
- `PlatformIO IDE <https://platformio.org/platformio-ide?utm_source=arduino-esp8266>`__
- `PlatformIO Core <https://docs.platformio.org/en/latest/core.html?utm_source=arduino-esp8266>`__ (command line tool)
- `Advanced usage <https://docs.platformio.org/en/latest/platforms/espressif8266.html?utm_source=arduino-esp8266>`__ - custom settings, uploading to LittleFS, Over-the-Air (OTA), staging version
- `Integration with Cloud and Standalone IDEs <https://docs.platformio.org/en/latest/ide.html?utm_source=arduino-esp8266>`__ - Cloud9, Codeanywhere, Eclipse Che (Codenvy), Atom, CLion, Eclipse, Emacs, NetBeans, Qt Creator, Sublime Text, VIM, Visual Studio, and VSCode
- `Project Examples <https://docs.platformio.org/en/latest/platforms/espressif8266.html?utm_source=arduino-esp8266#examples>`__

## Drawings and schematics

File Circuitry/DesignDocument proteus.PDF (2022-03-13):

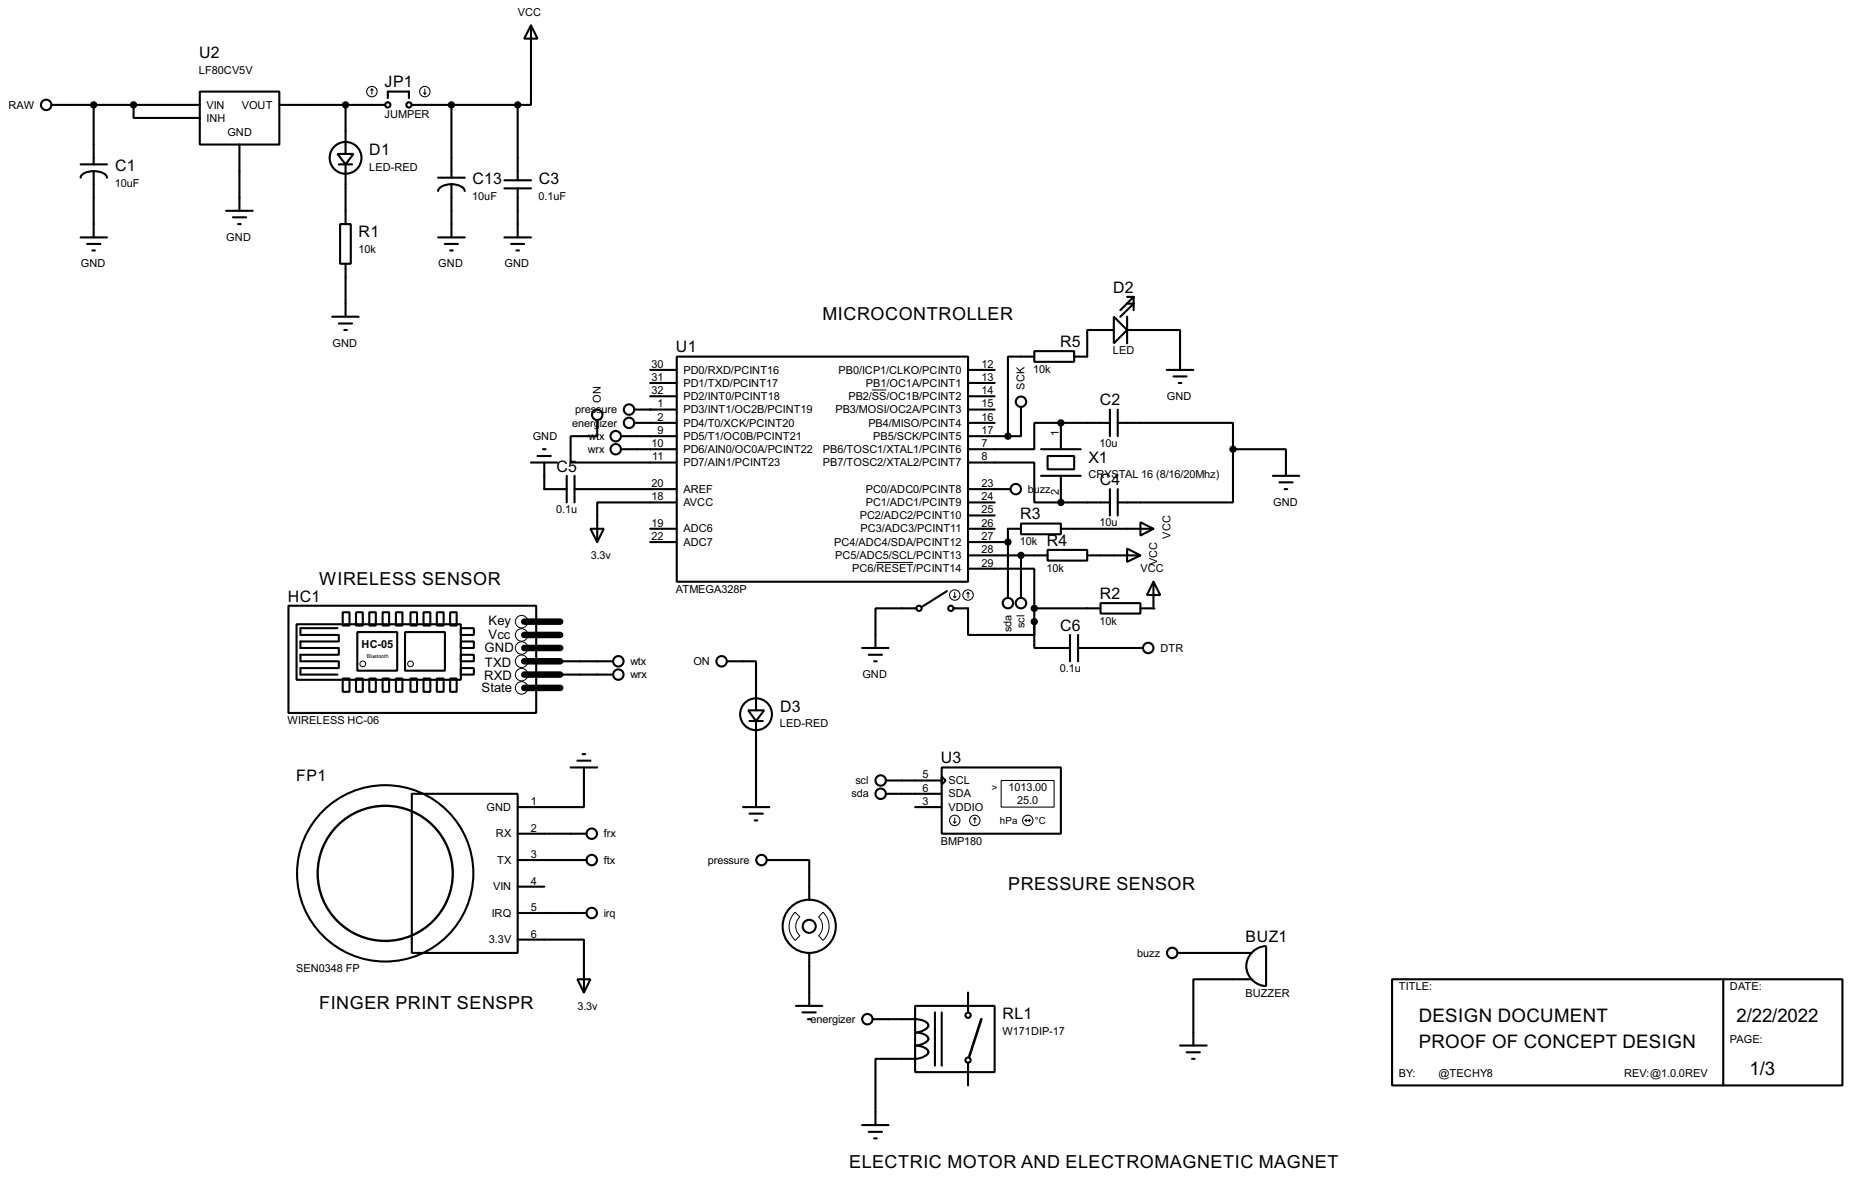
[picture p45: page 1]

TITLE:
PAGE: DESIGN DOCUMENT
PROOF OF CONCEPT DESIGN

ELECTRIC MOTOR AND ELECTROMAGNETIC MAGNET

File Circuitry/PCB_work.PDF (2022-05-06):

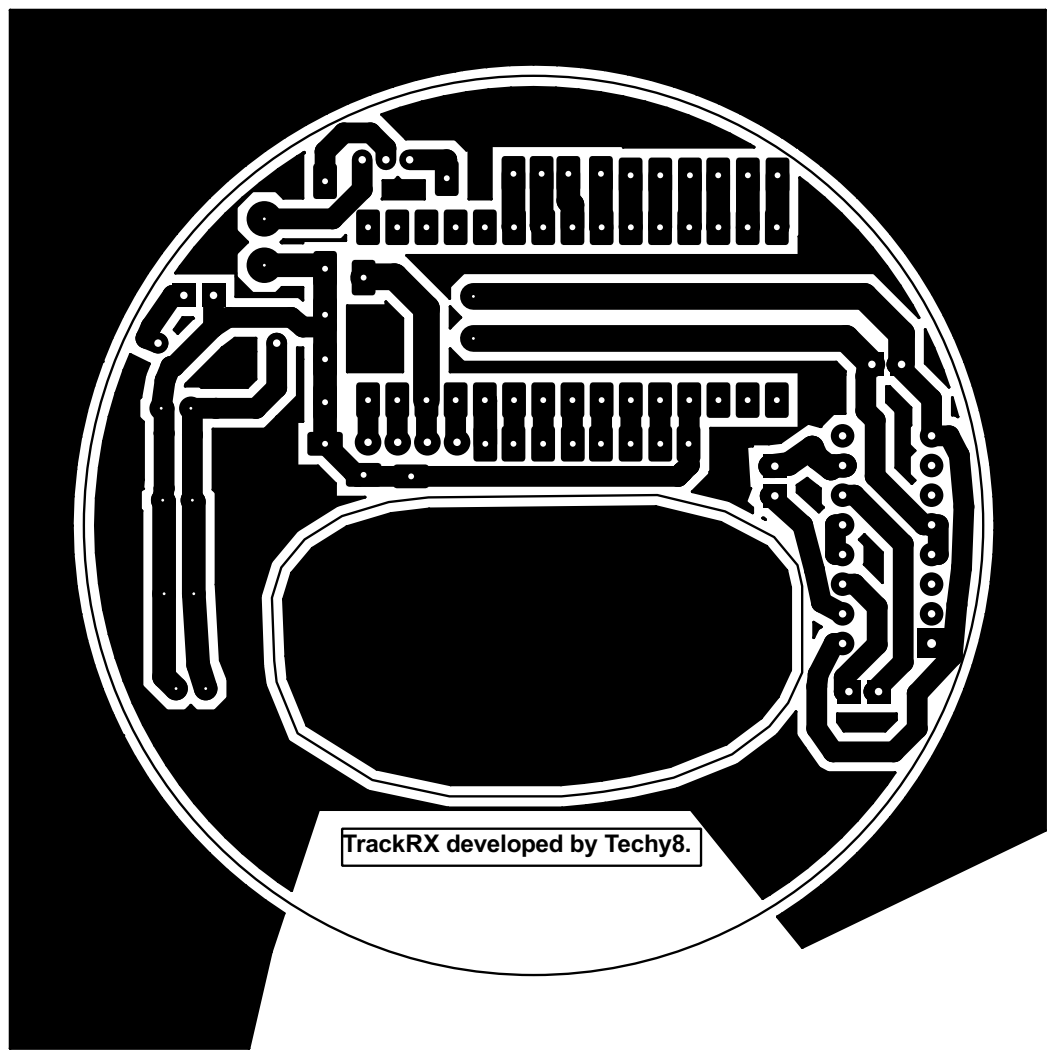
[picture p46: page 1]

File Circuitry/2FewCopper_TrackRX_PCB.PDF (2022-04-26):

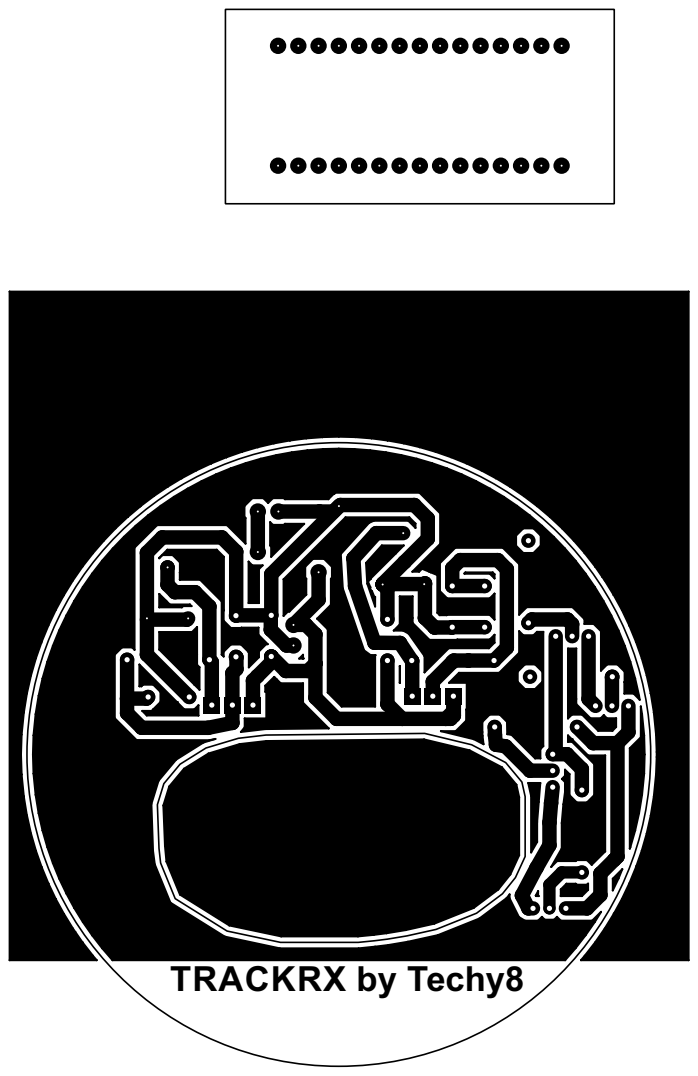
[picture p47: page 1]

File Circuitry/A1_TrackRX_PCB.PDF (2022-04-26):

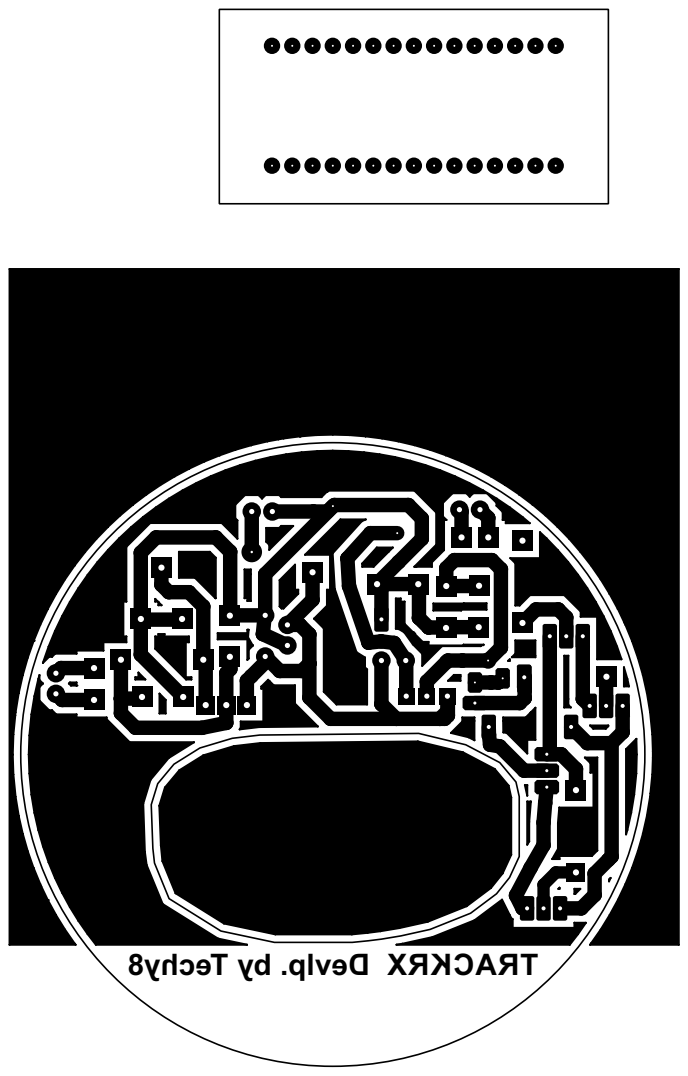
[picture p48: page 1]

8yhceT yb. pl ve D XRKCART

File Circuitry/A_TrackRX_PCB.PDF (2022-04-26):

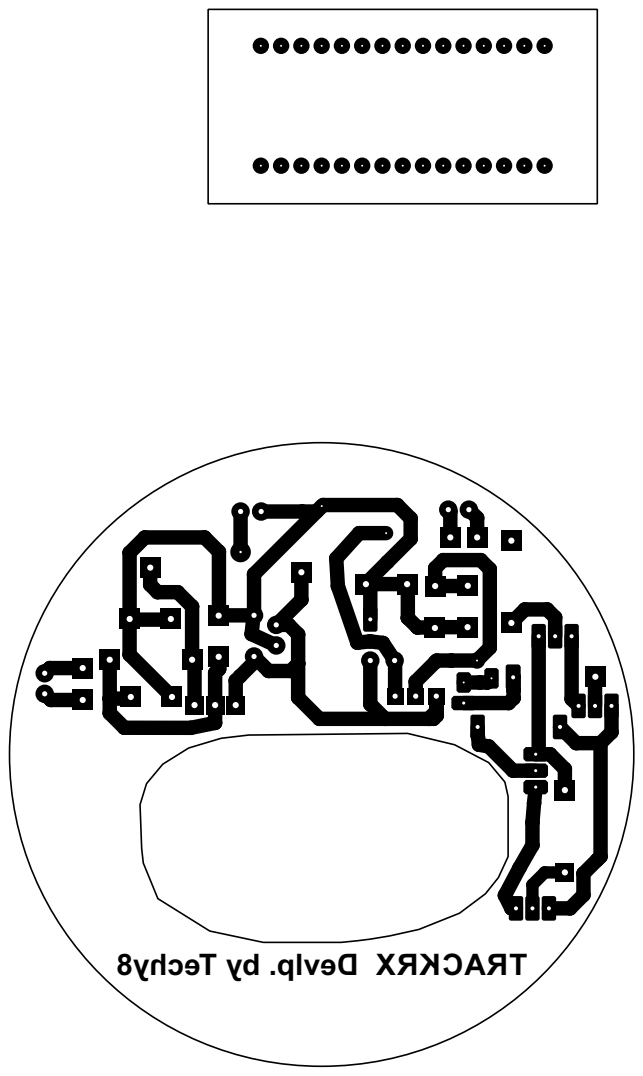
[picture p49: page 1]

8yhceT yb. pl ve D XRKCART

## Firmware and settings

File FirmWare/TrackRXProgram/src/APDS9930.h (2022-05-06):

/**
 * @file    APDS-9930.h
 * @brief   Library for the SparkFun APDS-9930 breakout board
 * @author  Shawn Hymel (SparkFun Electronics)
 *
 * @copyright	This code is public domain but you buy me a beer if you use
 * this and we meet someday (Beerware license).
 *
 * This library interfaces the Avago APDS-9930 to Arduino over I2C. The library
 * relies on the Arduino Wire (I2C) library. to use the library, instantiate an
 * APDS9930 object, call init(), and call the appropriate functions.
 */
 
#ifndef APDS9930_H
#define APDS9930_H

#include <Arduino.h>

/* Debug */
#define DEBUG                   0

/* APDS-9930 I2C address */
#define APDS9930_I2C_ADDR       0x39

/* Command register modes */
#define REPEATED_BYTE           0x80
#define AUTO_INCREMENT          0xA0
#define SPECIAL_FN              0xE0

/* Error code for returned values */
#define ERROR                   0xFF

/* Acceptable device IDs */
#define APDS9930_ID_1           0x12
#define APDS9930_ID_2           0x39

/* Misc parameters */
#define FIFO_PAUSE_TIME         30      // Wait period (ms) between FIFO reads

/* APDS-9930 register addresses */
#define APDS9930_ENABLE         0x00
#define APDS9930_ATIME          0x01
#define APDS9930_PTIME          0x02
#define APDS9930_WTIME          0x03
#define APDS9930_AILTL          0x04
#define APDS9930_AILTH          0x05
#define APDS9930_AIHTL          0x06
#define APDS9930_AIHTH          0x07
#define APDS9930_PILTL          0x08
#define APDS9930_PILTH          0x09
#define APDS9930_PIHTL          0x0A
#define APDS9930_PIHTH          0x0B
#define APDS9930_PERS           0x0C
#define APDS9930_CONFIG         0x0D
#define APDS9930_PPULSE         0x0E
#define APDS9930_CONTROL        0x0F
#define APDS9930_ID             0x12
#define APDS9930_STATUS         0x13
#define APDS9930_Ch0DATAL       0x14
#define APDS9930_Ch0DATAH       0x15
#define APDS9930_Ch1DATAL       0x16
#define APDS9930_Ch1DATAH       0x17
#define APDS9930_PDATAL         0x18
#define APDS9930_PDATAH         0x19
#define APDS9930_POFFSET        0x1E


/* Bit fields */
#define APDS9930_PON            0b00000001
#define APDS9930_AEN            0b00000010
#define APDS9930_PEN            0b00000100
#define APDS9930_WEN            0b00001000
#define APSD9930_AIEN           0b00010000
#define APDS9930_PIEN           0b00100000
#define APDS9930_SAI            0b01000000

/* On/Off definitions */
#define OFF                     0
#define ON                      1

/* Acceptable parameters for setMode */
#define POWER                   0
#define AMBIENT_LIGHT           1
#define PROXIMITY               2
#define WAIT                    3
#define AMBIENT_LIGHT_INT       4
#define PROXIMITY_INT           5
#define SLEEP_AFTER_INT         6
#define ALL                     7

/* LED Drive values */
#define LED_DRIVE_100MA         0
#define LED_DRIVE_50MA          1
#define LED_DRIVE_25MA          2
#define LED_DRIVE_12_5MA        3

/* Proximity Gain (PGAIN) values */
#define PGAIN_1X                0
#define PGAIN_2X                1
#define PGAIN_4X                2
#define PGAIN_8X                3

/* ALS Gain (AGAIN) values */
#define AGAIN_1X                0
#define AGAIN_8X                1
#define AGAIN_16X               2
#define AGAIN_120X              3

/* Interrupt clear values */
#define CLEAR_PROX_INT          0xE5
#define CLEAR_ALS_INT           0xE6
#define CLEAR_ALL_INTS          0xE7

/* Default values */
#define DEFAULT_ATIME           0xED
#define DEFAULT_WTIME           0xFF
#define DEFAULT_PTIME           0xFF
#define DEFAULT_PPULSE          0x08
#define DEFAULT_POFFSET         0       // 0 offset
#define DEFAULT_CONFIG          0
#define DEFAULT_PDRIVE          LED_DRIVE_12_5MA
#define DEFAULT_PDIODE          2
#define DEFAULT_PGAIN           PGAIN_1X
#define DEFAULT_AGAIN           AGAIN_1X
#define DEFAULT_PILT            0       // Low proximity threshold
#define DEFAULT_PIHT            50      // High proximity threshold
#define DEFAULT_AILT            0xFFFF  // Force interrupt for calibration
#define DEFAULT_AIHT            0
#define DEFAULT_PERS            0x22    // 2 consecutive prox or ALS for int.

/* ALS coefficients */
#define DF                      52
#define GA                      0.49
#define ALS_B                       1.862
#define ALS_C                       0.746
#define ALS_D                       1.291

/* State definitions */
enum {
  NOTAVAILABLE_STATE,
  NEAR_STATE,
  FAR_STATE,
  ALL_STATE
};

#ifdef _AVR_IO_H_
    // Do not use this alias as it's deprecated
    #define NA_STATE NOTAVAILABLE_STATE
#endif

/* APDS9930 Class */
class APDS9930 {
public:

    /* Initialization methods */
    APDS9930();
    ~APDS9930();
    bool init();
    uint8_t getMode();
    bool setMode(uint8_t mode, uint8_t enable);
    
    /* Turn the APDS-9930 on and off */
    bool enablePower();
    bool disablePower();
    
    /* Enable or disable specific sensors */
    bool enableLightSensor(bool interrupts = false);
    bool disableLightSensor();
    bool enableProximitySensor(bool interrupts = false);
    bool disableProximitySensor();

    /* LED drive strength control */
    uint8_t getLEDDrive();
    bool setLEDDrive(uint8_t drive);
    // uint8_t getGestureLEDDrive();
    // bool setGestureLEDDrive(uint8_t drive);
    
    /* Gain control */
    uint8_t getAmbientLightGain();
    bool setAmbientLightGain(uint8_t gain);
    uint8_t getProximityGain();
    bool setProximityGain(uint8_t gain);
    bool setProximityDiode(uint8_t drive);
    uint8_t getProximityDiode();

    
    /* Get and set light interrupt thresholds */
    bool getLightIntLowThreshold(uint16_t &threshold);
    bool setLightIntLowThreshold(uint16_t threshold);
    bool getLightIntHighThreshold(uint16_t &threshold);
    bool setLightIntHighThreshold(uint16_t threshold);
    
    /* Get and set interrupt enables */
    uint8_t getAmbientLightIntEnable();
    bool setAmbientLightIntEnable(uint8_t enable);
    uint8_t getProximityIntEnable();
    bool setProximityIntEnable(uint8_t enable);
    
    /* Clear interrupts */
    bool clearAmbientLightInt();
    bool clearProximityInt();
    bool clearAllInts();
    
    /* Proximity methods */
    bool readProximity(uint16_t &val);

    /* Ambient light methods */
    bool readAmbientLightLux(float &val);
    bool readAmbientLightLux(unsigned long &val);
    float floatAmbientToLux(uint16_t Ch0, uint16_t Ch1);
    unsigned long ulongAmbientToLux(uint16_t Ch0, uint16_t Ch1);
    bool readCh0Light(uint16_t &val);
    bool readCh1Light(uint16_t &val);
    
//private:

    /* Proximity Interrupt Threshold */
    uint16_t getProximityIntLowThreshold();
    bool setProximityIntLowThreshold(uint16_t threshold);
    uint16_t getProximityIntHighThreshold();
    bool setProximityIntHighThreshold(uint16_t threshold);
    
    /* Raw I2C Commands */
    bool wireWriteByte(uint8_t val);
    bool wireWriteDataByte(uint8_t reg, uint8_t val);
    bool wireWriteDataBlock(uint8_t reg, uint8_t *val, unsigned int len);
    bool wireReadDataByte(uint8_t reg, uint8_t &val);
    int wireReadDataBlock(uint8_t reg, uint8_t *val, unsigned int len);
};

#endif

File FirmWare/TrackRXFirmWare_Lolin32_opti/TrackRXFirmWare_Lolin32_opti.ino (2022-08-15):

#include "SmartCap.h"
#define timerPreload 80000000
#define timeTowait 5

#define BUZZER_PIN 5
#define BUZZER_CHANNEL 0

int removed_d=0;
uint16_t rt;
uint16_t rc;
http con= http();
volatile boolean flag = false;
uint16_t proximity_data = 0;
volatile boolean flag2 = false;
bool sta; 
bool flag_id = false; // Signed to a pill to check the difference by which one pill is preceeded by the next
uint32_t prev;
uint32_t dettectionTime_t;
//updater flag
bool updater = false;
char ck='0';
int quantity2;
void setup(){
  
  // put your setup code here, to run once:
  Serial.begin(9600);
  sGps.begin(9600);
  stream->begin(9600);
  nano.begin(9600);
  pinMode(APDS9930_INT, INPUT);
  pinMode(33, OUTPUT);
  digitalWrite(33, HIGH);
  delay(200);
//  pinMode(TX, FUNCTION_3);
//  pinMode(TX,INPUT);

  //   readGPS();
  //init GSM
  //  initGsm();
//  Serial.println(F("Get extra mem"));
  //    Serial.println(F("AT commands start"));
  readGPS();
  delay(10000);
  if (!con.isReady()) {
    Serial.println(F("MT not ready"));
  }
  Serial.println(F("AT commands ready Now!"));
  Serial.println(con.getSignal());
  net();
  intSensor();
  // Initiate HTTP/S session with the module

  
  char tkn[] = "device_id=888888";
  //Serial.println(ATH_URL);
  strcat(ATH_URL,tkn);
  Serial.print(F("posting at:"));
  Serial.println(ATH_URL);
  rt = con.doPostD(ATH_URL, content_appCoded, 10000, 10000);
  while (rt != 200) {
    Serial.println(F("."));
    rt = con.doPostD(ATH_URL, content_appCoded, 10000, 10000);
    Serial.println(rt);
    if (rt >= 300 && rt <= 710) {
      Serial.println(F("Reconnecting..."));
      reconnect(apn);
    }
    Serial.print(rt);
    Serial.println(F("couldn't post"));
  }
  Serial.print(F(" data size: ")); Serial.println(con.getDataSizeReceived());
  const String jsResp = con.getDataReceived();
  quantity = jsonExtract(jsResp, "initialQuantity").toInt();
  t = jsonExtract(jsResp, "token");
  
  Serial.print(F("pills quantity: ")); Serial.println(quantity);
  Serial.print(F("token: ")); Serial.println(t);
  attachInterrupt(13, sens, FALLING);
  //sensing enclosure opened.
  attachInterrupt(33, trigger, RISING);
  //sensing object dettection

  
  Serial.println("Interrupt should start");
  sta = true;
  quantity2 = quantity;
//  interrupts();
}

void loop() {
  prev = 0;
  dettectionTime_t = 0;
  if(flag){
    Serial.println(F("cap opened..."));
    /* if the cap is opened, start the sensor:
     *  Do not do anything else than just checking pill dispense
     *  - flag2 is sensor
     *  - flag is cap opening(Triggerer) Closed and Opened
     *  
     *  if cap is opened, then, it means fP has been accepted,
     *  that means, the opening Trigger value has changed.
     *  if it has changed,:
     *  - Start running the sensor
     *  - init a value called checker, make it true
     *  - flag of trigger back to zero
     *  - if flag of trigger back to zero, changes back, and 
     *  the operation is still in while loops, exit while loop,
     *  since the cap has been closed(Trigger value changed)
     *  
     *  
     */
    Serial.println("Cap opened");
    flag = false;
    bool checker = true;
    while(checker){
       if(digitalRead(33) == LOW){
        nano.write("5");
        Serial.println("Wrote 5 to nano");
        checker = false;
        Serial.println("Cap closed");
      }
      Serial.println(F("checkder..."));
      delay(250);

      //Time before pill is out
      //time 
      if(flag2){
        //record the value to be substructed from the initial quantity
        int returnedValue = somaNumber();
        
        //time when something is dettected going out.
        uint32_t trigT = millis();// this time
        
        Serial.print("prev Dettection: ");Serial.println(dettectionTime_t);
        Serial.print("current Dettect now: ");Serial.println(trigT);
        //time difference since last dettection
        uint32_t interv = trigT - dettectionTime_t;
        
        // allowed difference in time so as to substract from initial quantity
        uint32_t allowed_difference = 266;

        if(interv > allowed_difference){
          Serial.print("differ time: ");Serial.println(interv);
          Serial.print("Previous quantity: ");
          Serial.println(quantity2);
          Serial.print("current ");
          Serial.println(quantity);
          quantity = quantity - returnedValue;
        // send 0 if everyThing has been removed quantity
          if(quantity <= 0){
            quantity = 0;
            //removed_d+1;
            removed_d = 0;       
          }
          updater = true;
        }
        Serial.println("one");
      }

      if(flag_id){
        // when dettection occur, record the time
        dettectionTime_t = millis();
        flag_id = false;
      }
      
      else{
      }

    }
  }

  if(updater){
    /*updater will be run only when the buzzer is triggered or 
    some pills have just been taken out of the bottle*/
    
    Serial.println(F("updating cap"));
    updateCap();
    updater = false;
  }else{
    
    Serial.println(F("Buzzer"));
    buzzer();
  }
  if(sta){
    nano.write("R");
    sta = false;
  }
}

ICACHE_RAM_ATTR void sens(){
  flag2 = true;
//  quantity = quantity - ((int)somaNumber());  
}
ICACHE_RAM_ATTR void trigger(){
  flag = true;
  
}
void updateCap(){
  
  //update cup
  Serial.println(F("updateCup"));
  String dt = "finger_print=" + t + "&quantity=" + String(quantity) +
              "&lat=" + String(gps_lat, 7) + "&lon=" + String(gps_lon, 7) + "&token=" + t;

  char dataTosend[(dt.length()) + 1];

  strcpy(dataTosend, dt.c_str());
//  strcat(URL,dt.c_str());
  Serial.print(URL);
  Serial.println(dataTosend);
  rt = con.doPostDU(URL,dataTosend,content_appCoded, 2000, 3000);
  
  while (rt != 200) {

    if (rt >= 300 && rt <= 710) {
      Serial.println(F("Reconnecting..."));
      reconnect(apn);
    }
    if(rt == 403){
      Serial.println(F("no updates..."));
      break;
    }
    rt = con.doPostDU(URL,dataTosend, content_appCoded,5000, 10000);
    Serial.println(rt);
  }
  
  Serial.println(F("updated successfully"));
//  Serial.println(con.getDataSizeReceived());
//  Serial.println(con.getDataReceived());

}

void buzzer() {
  String stat = "value=&token=" + t;
  char ch[(stat.length()) + 1];
  strcpy(ch, stat.c_str());
//  strcat(buzz, ch);
//  Serial.print(F("buzzer at:"));
//  Serial.print(buzz);Serial.println(ch);
  uint16_t rc = con.doPostDU(buzz,ch, content_appCoded,2000, 3000);

  while (rc != 200) {
    //    net();
    if (rt >= 300 && rt <= 710) {
      Serial.println(F("Reconnecting..."));
      reconnect(apn);
    }
    Serial.println(rc);
    rc = con.doPostDU(buzz,ch, content_appCoded,5000, 6000);
  }
//  const size_t cap = getDataSizeReceived();
  buzzinger = jsonExtract(con.getDataReceived(), "value").toInt();
  if (buzzinger == 1) {
    //Read GPS data when buzzer is requested.
    Serial.println(F("GPS data: "));
    sGps.listen();
    readGPS();
    
    //enable updating feature everytime the buzzer is triggered.
    updater = true;
    Serial.println(F("Writing to buzzer"));
    
    while(buzzinger==1){
      tone(BUZZER_PIN, NOTE_G1, 500, BUZZER_CHANNEL);
      noTone(BUZZER_PIN, BUZZER_CHANNEL);
      tone(BUZZER_PIN, NOTE_A2, 500, BUZZER_CHANNEL);
      noTone(BUZZER_PIN, BUZZER_CHANNEL);
      tone(BUZZER_PIN, NOTE_B3, 500, BUZZER_CHANNEL);
      noTone(BUZZER_PIN, BUZZER_CHANNEL);
      tone(BUZZER_PIN, NOTE_G1, 500, BUZZER_CHANNEL);
      noTone(BUZZER_PIN, BUZZER_CHANNEL);
      tone(BUZZER_PIN, NOTE_G1, 500, BUZZER_CHANNEL);
      noTone(BUZZER_PIN, BUZZER_CHANNEL);
      tone(BUZZER_PIN, NOTE_A2, 500, BUZZER_CHANNEL);
      noTone(BUZZER_PIN, BUZZER_CHANNEL);
      tone(BUZZER_PIN, NOTE_B3, 500, BUZZER_CHANNEL);
      noTone(BUZZER_PIN, BUZZER_CHANNEL);
      tone(BUZZER_PIN, NOTE_G1, 500, BUZZER_CHANNEL);
      noTone(BUZZER_PIN, BUZZER_CHANNEL);
      tone(BUZZER_PIN, NOTE_B2, 500, BUZZER_CHANNEL);
      noTone(BUZZER_PIN, BUZZER_CHANNEL);
      tone(BUZZER_PIN, NOTE_C3, 500, BUZZER_CHANNEL);
      noTone(BUZZER_PIN, BUZZER_CHANNEL);
      tone(BUZZER_PIN, NOTE_D4, 500, BUZZER_CHANNEL);
      noTone(BUZZER_PIN, BUZZER_CHANNEL);
      rc = con.doPostDU(buzz,ch, content_appCoded,5000, 6000);
      while (rc != 200) {
        //    net();
        if (rt >= 300 && rt <= 710) {
          Serial.println(F("Reconnecting..."));
          reconnect(apn);
        }
        Serial.println(rc);
        rc = con.doPostDU(buzz,ch, content_appCoded,5000, 6000);
      }
      buzzinger = jsonExtract(con.getDataReceived(), "value").toInt();
    }

  }else if(buzzinger == 4){
    Serial.println(F("Writing 4 to nano, bottom lock"));
    nano.write("4");
    reuploadZero();
  }else if(buzzinger == 2){
    Serial.println(F("Sending delete fingerprint"));
    nano.write("2");
    reuploadZero();
  }else if(buzzinger == 3){
    Serial.println(F("Sending register fingerprint"));
    nano.write("3");
    reuploadZero();
  }
  else {
    nano.write("0");
//    digitalWrite(16,LOW);
//    nano.write("0");
//    digitalWrite(4, 0);
  }
  Serial.print(F("Buzzer :"));
  Serial.println(buzzinger);

}

void reuploadZero(){
    Serial.println(F("Then reupload 0"));
    stat = "value=0&token=" + t;
    char ch[(stat.length()) + 1];
    strcpy(ch, stat.c_str());
  //  strcat(buzz, ch);
  //  Serial.print(F("buzzer at:"));
  //  Serial.print(buzz);Serial.println(ch);
    uint16_t rc = con.doPostDU(buzz,ch, content_appCoded,2000, 3000);
    while (rc != 200) {
      //    net();
      if (rt >= 300 && rt <= 710) {
        Serial.println(F("Reconnecting..."));
        reconnect(apn);
      }
      Serial.println(rc);
      rc = con.doPostDU(buzz,ch, content_appCoded,5000, 6000);
    }
    Serial.println(F("Successfully reuploaded 0"));
}
void net() {

  NetworkRegistration net = con.getRegistrationStatus();

  while (net != REGISTERED_HOME) {
    net = con.getRegistrationStatus();
  }
  Serial.println(F("Registered"));
  //setup GPRS internet apn
  con.disconnectGPRS();
  bool sucss = con.setupGPRS(apn);
  if(!sucss) {
    Serial.println("Getting internet...");
    sucss = con.setupGPRS(apn);
    delay(3000);
  }


  bool connected = con.connectGPRS();

  if (connected) {
    Serial.print(F("connected with ip"));
    Serial.println(con.getIP());
  }
  else {
    Serial.println(F("not connected"));
  }



}

void reconnect(const char *u){
  con.sendCommand_P(AT_CMD_HTTPTERM);
  if (!con.readResponseCheckAnswer_P(DEFAULT_TIMEOUT, AT_RSP_OK,2)){}
  con.disconnectGPRS();
  con.setupGPRS(u);
  if(con.connectGPRS()){
    Serial.println(con.getIP());
  }
  
}

//void ISR(void){
//  timer0_write(ESP.getCycleCount() + timerPreload * timeTowait);
//  flag = true;
//}

void intSensor() {

  Serial.println(F("------------------------------"));
  Serial.println(F("APDS-9930 - ProximityInterrupt"));
  Serial.println(F("------------------------------"));

  // Initialize APDS-9930 (configure I2C and initial values)
  if ( apds.init() ) {
    Serial.println(F("APDS-9930 initialization complete"));
  } else {
    Serial.println(F("Something went wrong during APDS-9930 init!"));
  }
  
  // Adjust the Proximity sensor gain
  if ( !apds.setProximityGain(PGAIN_2X) ) {
    Serial.println(F("Something went wrong trying to set PGAIN"));
  }
  
  // Set proximity interrupt thresholds
  if ( !apds.setProximityIntLowThreshold(PROX_INT_LOW) ) {
    Serial.println(F("Error writing low threshold"));
  }
  if ( !apds.setProximityIntHighThreshold(PROX_INT_HIGH) ) {
    Serial.println(F("Error writing high threshold"));
  }
  
  // Start running the APDS-9930 proximity sensor (interrupts)
  if ( apds.enableProximitySensor(true) ) {
    Serial.println(F("Proximity sensor is now running"));
  } else {
    Serial.println(F("Something went wrong during sensor init!"));
  }
  if ( !apds.clearProximityInt() ) {
    Serial.println("Error clearing interrupt");
  }

#ifdef DUMP_REGS
  /* Register dump */
  uint8_t reg;
  uint8_t val;

  for(reg = 0x00; reg <= 0x19; reg++) {
    if( (reg != 0x10) && \
        (reg != 0x11) )
    {
      apds.wireReadDataByte(reg, val);
      Serial.print(reg, HEX);
      Serial.print(": 0x");
      Serial.println(val, HEX);
    }
  }
  apds.wireReadDataByte(0x1E, val);
  Serial.print(0x1E, HEX);
  Serial.print(": 0x");
  Serial.println(val, HEX);
#endif
}

uint16_t a = 0;
bool vl= 0;

int somaNumber(){
  int chek;
  // Read proximity level and print it out
  if ( !apds.readProximity(proximity_data) ) {
    Serial.println("Error reading proximity value");
    return 0;
  } else {
    Serial.print("Proximity detected! Level: ");
    Serial.println(proximity_data);
    if(proximity_data >= 200){
      prev = millis();
      chek = 1;

      //flag to record when something passes the sensor
      flag_id = true;
      removed_d+=1;
    }
    else{
      chek = 0;
    }
    
  } 
  
  
  // Reset flag and clear APDS-9930 interrupt (IMPORTANT!)
  flag2 = false;
  
  if ( !apds.clearProximityInt() ) {
    Serial.println("Error clearing interrupt");
  }

  return chek;
 
}

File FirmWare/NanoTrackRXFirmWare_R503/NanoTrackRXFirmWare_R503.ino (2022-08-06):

#include "WirelessConnect.h"

//String desc;
uint8_t ret;
void setup() {

  //  DDRD &= ~(1 << IRQ);
  //  PORTB != (1 << IRQ);
  /*Init print serial*/
  Serial.begin(9600);
  D1Mini.begin(9600);
  Serial.println("initializing ....");
  //intializeFP sensor
  initFP();
  pinMode(4, OUTPUT);
  pinMode(5, OUTPUT);
  pinMode(A0, OUTPUT);
  pinMode(7, OUTPUT);
  pinMode(6, OUTPUT);
  pinMode(9, OUTPUT);
  pinMode(8, OUTPUT);
  Serial.println("connected!");
  Serial.println("interrupt set");

  attachInterrupt(digitalPinToInterrupt(IRQ), trigger, FALLING);

}

//Blue LED Comparison mode  Yellow LED Registration mode  Red Deletion mode
void loop() {

  int select = sikiliza();

  if(select == 2){
    Serial.println("Selected delete");
    deleteFingerprint();
  }
  if (flag == 1) {
    Serial.println("Sensed your finger!");
    mySerial.listen();
    fingerPrint(select);
    delay(1500);
    flag = 0;
    
  }


//  if(somaNumber()) {
//    Serial.println("Writing to d1..");
//    D1Mini.write("1111");
//    delay(250);
//  }

}

void trigger() {
  flag = 1;
}
void fingerPrint(int slct) {
  ret = 0;
//  fingerprint.ctrlLED(fingerprint.eBreathing, fingerprint.eLEDBlue, 0);
  Serial.println("Please put your finger on the fingerPrint sensor");

//  if ((fingerprint.collectionFingerprint(0) != ERR_ID809)) {

  switch (slct){
    case 3:
      while(!registerFingerprint());
      break;
    default:
      fingerMatch();
  }

//  }
//  else {
//    Serial.println("Try again..");
//  }
//  fingerprint.ctrlLED(/*LEDMode = */fingerprint.eNormalClose, /*LEDColor = */fingerprint.eLEDBlue, /*blinkCount = */0);
  
}

//Fingerprint Registration
uint8_t registerFingerprint(){
  finger.LEDcontrol(FINGERPRINT_LED_GRADUAL_ON, 100, FINGERPRINT_LED_PURPLE);
  int p = -1;
  Serial.println("starting reg...");
  Serial.print("Waiting for valid finger to enroll as #"); Serial.println(fpNumber);
  while (p != FINGERPRINT_OK) {
    p = finger.getImage();
    switch (p) {
    case FINGERPRINT_OK:
      Serial.println("Image taken");
      break;
    case FINGERPRINT_NOFINGER:
      Serial.println(".");
      break;
    case FINGERPRINT_PACKETRECIEVEERR:
      Serial.println("Communication error");
      break;
    case FINGERPRINT_IMAGEFAIL:
      Serial.println("Imaging error");
      break;
    default:
      Serial.println("Unknown error");
      break;
    }
  }

  // OK success!

  p = finger.image2Tz(1);
  switch (p) {
    case FINGERPRINT_OK:
      Serial.println("Image converted");
      break;
    case FINGERPRINT_IMAGEMESS:
      Serial.println("Image too messy");
      return p;
    case FINGERPRINT_PACKETRECIEVEERR:
      Serial.println("Communication error");
      return p;
    case FINGERPRINT_FEATUREFAIL:
      Serial.println("Could not find fingerprint features");
      return p;
    case FINGERPRINT_INVALIDIMAGE:
      Serial.println("Could not find fingerprint features");
      return p;
    default:
      Serial.println("Unknown error");
      return p;
  }
  finger.LEDcontrol(FINGERPRINT_LED_FLASHING, 25, FINGERPRINT_LED_RED, 10);

  Serial.println("Remove finger");
  delay(2000);
  p = 0;
  while (p != FINGERPRINT_NOFINGER) {
    p = finger.getImage();
  }
  Serial.print("ID "); Serial.println(fpNumber+1);
  p = -1;
  Serial.println("Place same finger again");
  while (p != FINGERPRINT_OK) {
    p = finger.getImage();
    switch (p) {
    case FINGERPRINT_OK:
      Serial.println("Image taken");
      break;
    case FINGERPRINT_NOFINGER:
      Serial.print(".");
      break;
    case FINGERPRINT_PACKETRECIEVEERR:
      Serial.println("Communication error");
      break;
    case FINGERPRINT_IMAGEFAIL:
      Serial.println("Imaging error");
      break;
    default:
      Serial.println("Unknown error");
      break;
    }
  }

  // OK success!

  p = finger.image2Tz(2);
  switch (p) {
    case FINGERPRINT_OK:
      Serial.println("Image converted");
      break;
    case FINGERPRINT_IMAGEMESS:
      Serial.println("Image too messy");
      return p;
    case FINGERPRINT_PACKETRECIEVEERR:
      Serial.println("Communication error");
      return p;
    case FINGERPRINT_FEATUREFAIL:
      Serial.println("Could not find fingerprint features");
      return p;
    case FINGERPRINT_INVALIDIMAGE:
      Serial.println("Could not find fingerprint features");
      return p;
    default:
      Serial.println("Unknown error");
      return p;
  }

  // OK converted!
  Serial.print("Creating model for #");  Serial.println(fpNumber+1);

  p = finger.createModel();
  if (p == FINGERPRINT_OK) {
    Serial.println("Prints matched!");
  } else if (p == FINGERPRINT_PACKETRECIEVEERR) {
    Serial.println("Communication error");
    return p;
  } else if (p == FINGERPRINT_ENROLLMISMATCH) {
    Serial.println("Fingerprints did not match");
    return p;
  } else {
    Serial.println("Unknown error");
    return p;
  }

  Serial.print("ID "); Serial.println(fpNumber+1);
  p = finger.storeModel(fpNumber+1);
  if (p == FINGERPRINT_OK) {
    Serial.println("Stored!");
  } else if (p == FINGERPRINT_PACKETRECIEVEERR) {
    Serial.println("Communication error");
    return p;
  } else if (p == FINGERPRINT_BADLOCATION) {
    Serial.println("Could not store in that location");
    return p;
  } else if (p == FINGERPRINT_FLASHERR) {
    Serial.println("Error writing to flash");
    return p;
  } else {
    Serial.println("Unknown error");
    return p;
  }
  finger.LEDcontrol(FINGERPRINT_LED_FLASHING, 25, FINGERPRINT_LED_BLUE, 10);
  return true;
}

uint32_t st = 0;
void deleteFingerprint(){
  Serial.println("Stating delete...");
  uint8_t p = -1;

  for(int i = 1; i <= 5; i ++){

    p = finger.deleteModel(i);
      
    if (p == FINGERPRINT_OK) {
      Serial.print(i);Serial.println(": Deleted!");
    } else if (p == FINGERPRINT_PACKETRECIEVEERR) {
      Serial.println("Communication error");
    } else if (p == FINGERPRINT_BADLOCATION) {
      Serial.println("Could not delete in that location");
    } else if (p == FINGERPRINT_FLASHERR) {
      Serial.println("Error writing to flash");
    } else {
      Serial.print("Unknown error: 0x"); Serial.println(p, HEX);
    }
   
  }

//  if (finger.verifyPassword()) {
//    Serial.println("Found fingerprint sensor!");
//  } else {
//    Serial.println("Did not find fingerprint sensor :(");
//    while (1);
//  }
//
//  finger.emptyDatabase();
//  finger.LEDcontrol(FINGERPRINT_LED_GRADUAL_ON, 100, FINGERPRINT_LED_RED);
//  delay(1500);
//  finger.LEDcontrol(FINGERPRINT_LED_GRADUAL_OFF, 100, FINGERPRINT_LED_RED);
//  delay(1500);
//  Serial.println("Now database is empty :)");
}
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

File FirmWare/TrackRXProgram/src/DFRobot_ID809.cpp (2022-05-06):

/*!
 * @file DFRobot_ID809.cpp
 * @brief Define the basic structure of DFRobot_ID809 class and the implementation of underlying methods 
 * @copyright   Copyright (c) 2010 DFRobot Co.Ltd (http://www.dfrobot.com)
 * @licence     The MIT License (MIT)
 * @author [Eddard](eddard.liu@dfrobot.com)
 * @version  V1.0
 * @date  2020-03-19
 * @get from https://www.dfrobot.com
 * @url https://github.com/cdjq/DFRobot_ID809
 */

#include "DFRobot_ID809.h"
#include <Arduino.h>
#include <string.h>
#include <stdio.h>
Stream *dbg=NULL;

DFRobot_ID809::DFRobot_ID809()
  :s(NULL){
        
}

DFRobot_ID809::~DFRobot_ID809(){
        
}

bool DFRobot_ID809::begin(Stream &s_){
    s = &s_;
	String str = getDeviceInfo();
  //Serial.println(str[str.length()-1]);
  if(str[str.length()-1] == '4'){
	    
	   FINGERPRINT_CAPACITY   =    80 ;
	  
	  //Serial.println(str[str.length()-1]);
  }else if(str[str.length()-1] == '3'){
	  //Serial.println(str[str.length()-1]);
	   FINGERPRINT_CAPACITY  =   200 ;
	  
  }
	
    if(s == NULL){
        return false;
    }
    return true;
}

bool DFRobot_ID809::isConnected(){
    pCmdPacketHeader_t header = pack(CMD_TYPE, CMD_TEST_CONNECTION, NULL, 0);
    sendPacket(header);
    free(header);
    uint8_t ret = responsePayload(buf);
    LDBG("ret=");LDBG(ret);
    if(ret == ERR_SUCCESS){
        return true;
    }else{
        return false;
    }
}

uint8_t DFRobot_ID809::setDeviceID(uint8_t deviceID){
    uint8_t data[5] = {0};    //data:1bytes Parameter Type+4bytes Parameter Value
    data[1] = deviceID;
    uint8_t ret = setParam(data);
    return ret;
}

uint8_t DFRobot_ID809::setSecurityLevel(uint8_t securityLevel){
    uint8_t data[5] = {0};
    data[0] = 1;
    data[1] = securityLevel;
    uint8_t ret = setParam(data);
    return ret;
}

uint8_t DFRobot_ID809::setDuplicationCheck(uint8_t duplicationCheck){
    uint8_t data[5] = {0};
    data[0] = 2;
    data[1] = duplicationCheck;
    uint8_t ret = setParam(data);
    return ret;
}

uint8_t DFRobot_ID809::setBaudrate(eDeviceBaudrate_t baudrate){
    uint8_t data[5] = {0};
    data[0] = 3;
    data[1] = baudrate;
    uint8_t ret = setParam(data);
    return ret;
}

uint8_t DFRobot_ID809::setSelfLearn(uint8_t selfLearn){
    uint8_t data[5] = {0};
    data[0] = 4;
    data[1] = selfLearn;
    uint8_t ret = setParam(data);
    return ret;
}

uint8_t DFRobot_ID809::getDeviceID(){
    uint8_t data[1];  //data:1byte Parameter Type
    data[0] = 0;
    uint8_t ret = getParam(data);
    return ret;
}

uint8_t DFRobot_ID809::getSecurityLevel(){
    uint8_t data[1];
    data[0] = 1;
    uint8_t ret = getParam(data);
    return ret;
}

uint8_t DFRobot_ID809::getDuplicationCheck(){
    uint8_t data[1];
    data[0] = 2;
    uint8_t ret = getParam(data);
    return ret;
}

uint8_t DFRobot_ID809::getBaudrate(){
    uint8_t data[1];
    data[0] = 3;
    uint8_t ret = getParam(data);
    return ret;
}

uint8_t DFRobot_ID809::getSelfLearn(){
    uint8_t data[1];
    data[0] = 4;
    uint8_t ret = getParam(data);
    return ret;
}

String DFRobot_ID809::getDeviceInfo(){
    char *data;
    uint8_t result;
    pCmdPacketHeader_t header = pack(CMD_TYPE, CMD_DEVICE_INFO, NULL, 0);
    sendPacket(header);
    free(header);
    result = responsePayload(buf);
    LDBG("result=");LDBG(result);
    if(result != ERR_SUCCESS){
        return "";
    }
    uint16_t dataLen = buf[0]+(buf[1]<<8)+1;
    if((data = (char *)malloc(dataLen)) == NULL){
        LDBG("no memory!!!\r\n");
        while(1);
    }
    data[dataLen] = 0;
    result = responsePayload(data);
    LDBG("result=");LDBG(result);
    String ret = String(data);
    free(data);
    return ret;
}

uint8_t DFRobot_ID809::setModuleSN(const char* SN){
    char data[2];
    data[0] = MODULE_SN_SIZE;
    if(strlen(SN) > MODULE_SN_SIZE){
        LDBG("The serial number exceeds 15 characters");
        return ERR_ID809;
    }
    pCmdPacketHeader_t header = pack(CMD_TYPE, CMD_SET_MODULE_SN, data, 2);
    sendPacket(header);
    free(header);
    uint8_t ret = responsePayload(buf);
    LDBG("ret=");LDBG(ret);
    if(ret != ERR_SUCCESS){
        return ERR_ID809;
    }
    header = pack(DATA_TYPE, CMD_SET_MODULE_SN, SN, MODULE_SN_SIZE);
    sendPacket(header);
    free(header);
    ret = responsePayload(buf);
    LDBG("ret=");LDBG(ret);
    if(ret == ERR_SUCCESS){
        ret = buf[0];
    }
    return ret;
}

uint8_t DFRobot_ID809::getTemplate(uint16_t id,uint8_t * temp){
  char data[4];
  data[0] = id;
  data[1] = 0;
  data[2] = 0;
  data[3] = 0;
  pCmdPacketHeader_t header = pack(CMD_TYPE, CMD_LOAD_CHAR, data, 4);
  sendPacket(header);
  free(header);
  
  uint8_t ret = responsePayload(buf);
  LDBG("ret=");
  LDBG(ret);
  if(ret != ERR_SUCCESS) {
    return ERR_ID809;
  }
  data[0] = 0;
  data[1] = 0;
  header = pack(CMD_TYPE, CMD_UP_CHAR, data, 2);
  sendPacket(header);
  free(header);
  
  ret = responsePayload(buf);
  LDBG("ret=");
  LDBG(ret);
  if(ret == ERR_SUCCESS) {
    ret = buf[0];
  }
  ret = responsePayload(temp);

  return ret;
}
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

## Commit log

2022-03-13 poc deisgns and code as of 13 03 2022
    [Arduino_Nano.SLDPRT, Assem1_OP.SLDASM, Backup (1) of Arduino_Nano.SLDPRT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]
2022-03-20 Second push, version 4D6 cap and motor hols on opening section
    [Assembly_4Dft&fp.SLDASM, Backup (1) of Assembly_4Dft&fp.SLDASM, Backup (1) of Backup (1) of CupVersion4D6_withLocksM_2_fp&mt.SLDPRT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]
2022-03-20 Second push, version 4D6 cap and motor hols on opening section2
2022-04-26 update as of april 26 04 2022
    [2nd_Top_LockMechan_CupVersion4D6_withLocksM_2_fp&mt.STL, Assem1_OP.SLDASM, Assem_With_Top_lockMechanism.SLDASM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]
2022-05-06 update as of 06 may 2022
    [1 CapDesign_Version2.STL, 1-loCK_A_WithThin_CapDesign_Version6.STL, 1-loCK_B_CapDesign_Version6.STL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]
2022-05-22 Almost final version as of 22/05/2022
    [A.STL, A_locks_bottom_2.STL, Abigger_cap3_FingerPrintPart.STL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]
2022-06-18 As of of 18 may 2022 , 2 pcb in progress boards
    [1_bigger_cap4_auto_pillDisp.STL, 2_bigger_cap4_auto_pillDisp.STL, 3_bigger_cap4_auto_pillDisp.STL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]
